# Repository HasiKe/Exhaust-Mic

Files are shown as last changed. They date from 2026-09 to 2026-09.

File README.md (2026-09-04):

# Exhaust-Mic

**Zweikanaliger 24-Bit-Tonrekorder für Motor- und Auspuffgeräusche.**
Zwei Mikrofonköpfe mit 135 dBSPL Grenzschalldruck an einem Stereo-ADC,
aufgezeichnet von einem ESP32-S3 auf microSD — mit Zeitstempeln, die sich
im Schnittprogramm von selbst auf das Videomaterial legen.

Gebaut für eine Suzuki Hayabusa: Kopf A am Endrohr, Kopf B in der Airbox.

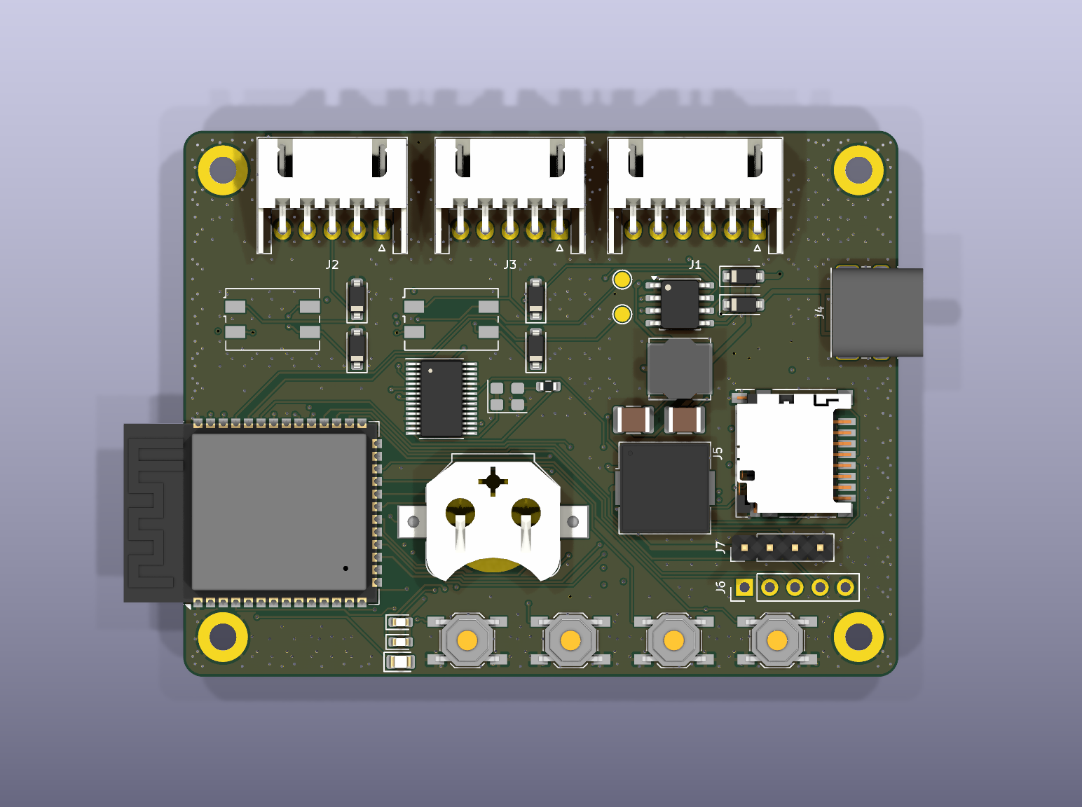
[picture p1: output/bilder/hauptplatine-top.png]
Hauptplatine von oben


---

## Auf einen Blick

| | |
|---|---|
| Kanäle | 2 × differentiell, 135 dBSPL Grenzschalldruck |
| Wandler | PCM1863, 24 Bit, 48 kHz, 110 dB Störabstand |
| Rechner | ESP32-S3-WROOM-1-N8R2, WLAN und Bluetooth LE |
| Speicher | microSD, WAV mit BWF-Zeitstempel |
| Zeitbasis | DS3231-TCXO, ±2 ppm, Sekundenanker auf die Samplenummer |
| Fahrzeug | CAN über SN65HVD230, Zündungs- und Bordnetzerkennung |
| Versorgung | 12 V Bordnetz, LM5164-Abwärtswandler, Verpolschutz |
| Einschalten | Zündung schaltet die Freigabe, Selbsthaltung bis die Datei zu ist, rechnerisch 30 µA im Ruhezustand |
| Hauptplatine | 72 × 55 mm, vier Lagen, beidseitig bestückt |
| Mikrofonkopf | 8 × 27 mm, zwei Lagen, 2× identisch |
| Gehäuse | fünf gedruckte Teile, Rundschnurdichtung |
| Bauteilkosten | rund 65 € Hauptplatine, 4 € je Mikrofonkopf |

## Bilder

| Hauptplatine, Rückseite | Mikrofonkopf |
|---|---|
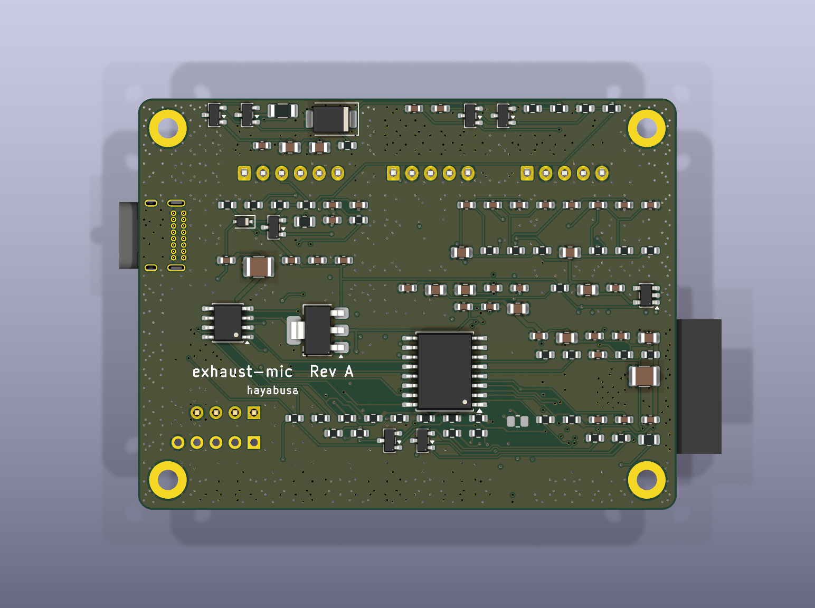
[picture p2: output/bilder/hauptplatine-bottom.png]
Rückseite
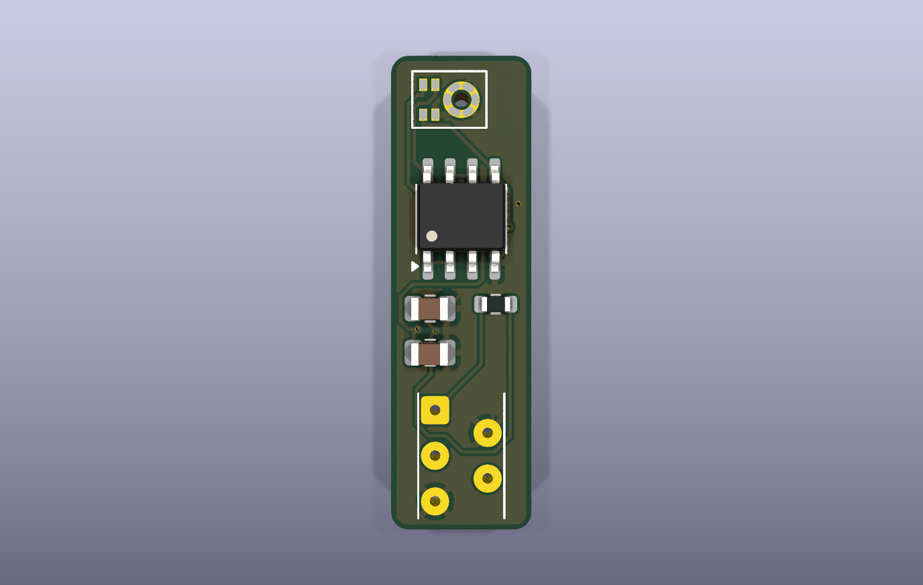
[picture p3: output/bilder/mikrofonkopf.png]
Mikrofonkopf
|  |  |

Alle Kabelstecker sitzen an der oberen Kante und zeigen nach außen, USB-C
und microSD liegen rechts hinter einer gemeinsamen Serviceklappe,
Leuchtdioden und Taster an der unteren Kante. Auf der Rückseite steht
nichts über 2,7 mm — der Aufbau bleibt mit 11,9 mm flach.

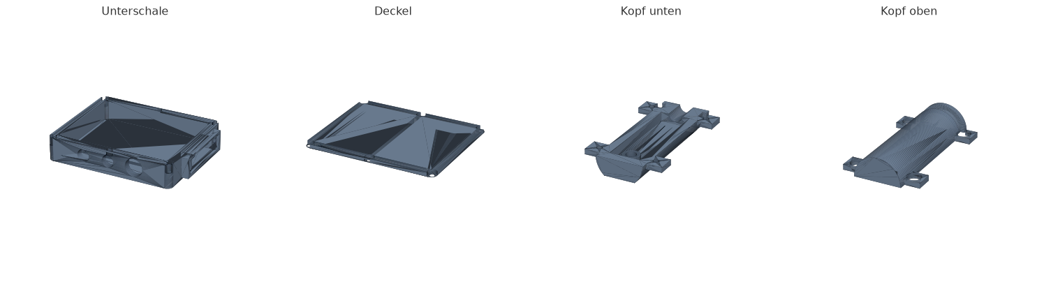
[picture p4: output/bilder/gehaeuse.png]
Gehäuseteile


## Wie das Signal läuft

```
Mikrofonkopf (2×)                    Hauptplatine
┌──────────────────────┐             ┌───────────────────────────────────┐
│ IM73A135  135 dBSPL  │  2× Twisted │  Gleichtaktdrossel + Klemmdioden  │
│   ↓                  │  Pair,      │        ↓                          │
│ OPA2325 Impedanz-    │──geschirmt──│  PCM1863  24 Bit / 48 kHz         │
│ wandler, 2,8-V-LDO   │  4 m        │        ↓ I²S                      │
└──────────────────────┘             │  ESP32-S3 ──► microSD (WAV/BWF)   │
                                     │        ↑                          │
                                     │  DS3231 1 Hz ─ Sekundenanker      │
                                     └───────────────────────────────────┘
```

Der Wandler ist Taktherr und hängt an einem eigenen 24,576-MHz-Oszillator;
der ESP32 empfängt nur. Die Sekundenflanke der Uhr latcht den laufenden
Samplezähler — das ergibt eine driftfreie Zuordnung Wanduhrzeit ↔ Sample
über die ganze Aufnahme, unabhängig vom Abtastratenfehler.

## Stand

| | Mikrofonkopf | Hauptplatine |
|---|---|---|
| Größe | 8 × 27 mm | 72 × 55 mm |
| Bauteile | 14 | 131 |
| Leiterbahnen | 120 (199 mm) | 1085 (3321 mm) |
| Durchkontaktierungen | 7 | 879 |
| Offene Verbindungen | **0** | **8** |
| DRC-Fehler | **0** | **0** |
| ERC-Fehler | **0** | **0** |
| Schaltplanparität | **0** | 6 |
| Bauhöhe oben / unten | 1,8 / 1,5 mm | 7,6 / 2,7 mm |

Der Mikrofonkopf ist fertig. Auf der Hauptplatine bleiben **acht
Verbindungen offen** — allesamt Stücke der Masseflächen, kein Pad und kein
Signalnetz. Sie sind in KiCads interaktivem Router in wenigen Minuten zu
schließen und müssen vor der Fertigung geschlossen sein.

Die sechs Abweichungen der Schaltplanparität sind die vier
Befestigungsbohrungen ohne Symbol und die Schirmanschlüsse von USB-C und
Kartenhalter, die der Footprint führt und das Symbol nicht.

Beschaffung: 71 von 76 Positionen haben eine bei DigiKey lagernde
Herstellernummer. Offen sind zwei: MK1 — das IM73A135V01XTSA1 ist aktiv,
bei DigiKey aber ohne Bestand, andere Distributoren führen es — und **R2
(680 k)**, das beim Umbau auf die Zündungsfreigabe seinen Wert gewechselt
hat und noch keine geprüfte Bestellnummer trägt.

> **Nichts davon ist bisher aufgebaut worden.** Geprüft sind DRC, ERC,
> Schaltplanparität, eine eigene Abnahme und der Übersetzungslauf der
> Firmware — keine Messung an echter Hardware.

## Was im Repository liegt

| | |
|---|---|
| `*.kicad_sch`, `exhaust-mic.kicad_pcb` | Hauptplatine, sechs Blätter |
| `mic-head/` | eigenes Projekt für den Mikrofonkopf |
| `lib/` | Symbole und Landmuster, die KiCad nicht mitbringt |
| `firmware/` | ESP-IDF-Firmware |
| `output/` | Stücklisten, Gerber, PDF, STEP/STL, Bilder |
| `docs/` | Beschaffung, Gehäuse, Entwicklungsnotizen |

Schaltplan, Layout, Gehäuse und die Pinbelegung der Firmware werden
**erzeugt, nicht von Hand gepflegt**. Jede Gehäuseöffnung und jeder GPIO
in der Firmware stammt aus der Platinendatei — wandert ein Stecker,
wandert alles mit. Das hat sich mehrfach ausgezahlt: die Stecker sind in
diesem Projekt zweimal komplett umgezogen.

## Selbst erzeugen

Schaltplan, Layout und Gehäuse entstehen aus Generatorskripten, die
**nicht im Repository liegen** (`tools/`, `case/`). Hier stehen ihre
Ergebnisse: die KiCad-Dateien, die Modelle und alles unter `output/`.
Die Firmware baut ohne sie:

```sh
# Firmware
. ~/esp/esp-idf/export.sh
cd firmware && idf.py set-target esp32s3 && idf.py build
```

⚠️ **Die Dateien auf der Platte sind weiter als die Generatoren.** In den
Schaltplänen stecken Beschaffungsfelder, korrigierte Landmuster, zwei
reparierte Symbole und fünf PWR_FLAG, die `build_main.py` überschreiben
würde. Vor einem Neulauf lesen: [`docs/entwicklung.md`](docs/entwicklung.md).

## Weiterlesen

| | |
|---|---|
| [`docs/beschaffung.md`](docs/beschaffung.md) | Bauteilwahl über die DigiKey-Schnittstelle, Ersatztypen, Bestand |
| [`docs/gehaeuse.md`](docs/gehaeuse.md) | Maße, Dichtkonzept, Filamentwahl, Temperaturgrenze am Endrohr |
| [`docs/entwicklung.md`](docs/entwicklung.md) | Werkzeugfallen, Leiterbahnbreiten, Prüfung, Schaltplan gegen Platine |
| [`firmware/README.md`](firmware/README.md) | Firmware, GoPro-Kopplung, Stand gegen die Anforderungen |
| [`docs/specs/…`](../../docs/specs/2026-08-28-exhaust-mic-design.md) | Auslegung, Rauschbudget, Pegelplan |
| [`CHANGELOG.md`](CHANGELOG.md) | Was in welcher Version dazukam, bekannte Einschränkungen |

## Zündung

Die Freigabe des Abwärtswandlers hängt an **Klemme 15**, die Versorgung
selbst an Klemme 30. Zündung an heißt anlaufen; Zündung aus heißt nicht
sofort stromlos, sondern: der ESP32 hält seine eigene Versorgung über
`PWR_HOLD` fest, schließt die Datei und lässt dann los. Im Ruhezustand
bleiben rechnerisch **30 µA** statt der rund 100 mA, die eine dauernd
laufende Platine zieht — vorher gab es kein Aus.

**Der Motor startet die Aufnahme.** Springt er an, hebt die Lichtmaschine
das Bordnetz von der Ruhespannung auf 14 V — das ist der dritte Auslöser
neben Taster und Kamera. Schwellen und Zeiten stehen in
[`firmware/README.md`](firmware/README.md#zündung-motorlauf-und-abschalten),
die Schaltung in
[`docs/entwicklung.md`](docs/entwicklung.md#die-zündung-schaltet-nicht-das-bordnetz).

## GoPro

Der Rekorder hängt sich über Bluetooth LE an die Open-GoPro-Schnittstelle
und meldet sich für den Kamerastatus an: **Video starten heißt Aufnahme
starten**, Stopp heißt Stopp. Der Taster am Gerät löst umgekehrt die
Kamera aus.

⚠️ Die Platine kann der Kamera **keinen Ton liefern**. Der ESP32-S3
beherrscht nur Bluetooth LE, GoPro nimmt drahtlosen Ton aber über HFP an —
ein Bluetooth-Classic-Profil. Und HFP wäre einkanalig mit 8 oder 16 kHz,
also das Gegenteil dessen, wofür diese Platine gebaut ist. Einzelheiten
und die zwei Auswege in [`firmware/README.md`](firmware/README.md).

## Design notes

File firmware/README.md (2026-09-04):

# Firmware

ESP-IDF v5.3.2, Ziel `esp32s3`. Baut warnungsfrei, 664 kB Abbild.

```sh
git clone --depth 1 -b v5.3.2 --recursive https://github.com/espressif/esp-idf ~/esp/esp-idf
~/esp/esp-idf/install.sh esp32s3
. ~/esp/esp-idf/export.sh
cd firmware && idf.py set-target esp32s3 && idf.py build
idf.py -p /dev/ttyACM0 flash monitor
```

## Die Pinbelegung wird erzeugt, nicht abgetippt

```sh
python3 firmware/tools/pins_aus_netzliste.py     # -> firmware/main/pins.h
```

Quelle ist `output/main.net`, also der Schaltplan. Der Header ist
mitversioniert: ein Diff zeigt sofort, wenn ein GPIO gewandert ist. Von
Hand geändert wird er nicht.

## Zündung, Motorlauf und Abschalten

Die Platine hängt mit `VBAT12` an Klemme 30, ihre Freigabe `EN/UVLO` aber
an Klemme 15 — Zündung an heißt anlaufen. Zündung aus würde den Strom
mitten im Schreiben abstellen, deshalb hält `PWR_HOLD` (GPIO42) die
Freigabe über D8 fest, bis die Datei zu ist. Der Aufbau steht in
[`docs/entwicklung.md`](../docs/entwicklung.md#die-zündung-schaltet-nicht-das-bordnetz).

`zuendung_selbsthaltung()` ist die **erste Zeile in `app_main`** — vor
allem anderen. Beim Anlassen bricht die Zündspannung ein; ohne die
Selbsthaltung fiele die Platine genau dann aus, wenn die Aufnahme
beginnen soll.

Gemessen wird über die beiden Teiler auf dem Versorgungsblatt:

| | Teiler | Bereich |
|---|---|---|
| Klemme 15 | R9 100k / R10 47k, Zenerklemme D5 | brauchbar bis rund 10 V, darüber gekappt |
| Bordnetz | R11 470k / R12 68k | ungekappt bis über 20 V |

Klemme 15 ist damit ein Anwesenheitsmelder, das Bordnetz eine Messung.
Daraus die drei Zustände:

| Zustand | Bedingung | Wirkung |
|---|---|---|
| `ZUENDUNG_AUS` | Klemme 15 unter 5 V für 2 s | Datei schließen, Selbsthaltung lösen |
| `ZUENDUNG_AN` | Klemme 15 über 7 V für 0,3 s | bereit, keine Aufnahme |
| `ZUENDUNG_MOTOR` | Bordnetz über 13,2 V für 2 s | Aufnahme läuft |

**Der Motor ist der dritte Auslöser** neben Taster und Kamera: springt er
an, hebt die Lichtmaschine das Bordnetz von der Ruhespannung (12,6 bis
12,8 V, direkt nach der Fahrt bis 13,0 V) auf 14,0 bis 14,4 V. 13,2 V
trennt beides. Zurück geht es erst unter 12,9 V und nach zehn Sekunden —
im Leerlauf mit Lüfter und Licht bricht die Spannung sonst kurz genug
ein, um die Aufnahme zu zerhacken.

Die Abschaltschwelle für Klemme 15 liegt mit 5 V bewusst tief: beim
Anlassen geht die Zündleitung mit dem Bordnetz in die Knie, und wer hier
9 V ansetzt, schaltet das Gerät genau beim Motorstart ab. Der
Schlüsseldreh dagegen fällt hart auf null.

Am Schreibtisch stört das nichts: `+4V6` kommt über D4 auch aus
`USB_VBUS`, und der Automat schaltet nur ab, wenn er die Zündung vorher
einmal gesehen hat. `PGOOD` sagt zusätzlich, ob der Abwärtswandler
regelt.

⚠️ **Die Werkskalibrierung des ADC ist Pflicht.** Ohne den eFuse-Wert
liegen die Spannungen um bis zu zehn Prozent daneben — das ist genau der
Abstand zwischen Ruhe- und Ladespannung. `zuendung_start()` gibt dann
einen Fehler zurück, statt zu raten.

## GoPro

### Was geht: Aufnahme automatisch mitlaufen lassen

Über Bluetooth LE nach der Open-GoPro-Schnittstelle. Der Rekorder meldet
sich für Statusänderungen an; sobald die Kamera zu kodieren beginnt,
startet die Aufnahme, und umgekehrt. Der Taster am Gerät löst zusätzlich
die Kamera aus.

Alle Kennungen stammen aus dem offiziellen SDK
(`open_gopro/models/constants/`), nicht aus dem Gedächtnis:

| | Wert |
|---|---|
| Dienst | `0000FEA6-0000-1000-8000-00805F9B34FB` |
| Merkmale | `b5f9XXXX-aa8d-11e3-9046-0002a5d5c51b`, XXXX = 0072 Befehl, 0073 Antwort, 0076 Abfrage, 0077 Antwort |
| Auslöser | `SET_SHUTTER` 0x01 |
| Statusabo | `REG_STATUS_VAL_UPDATE` 0x53, Rückmeldung `STATUS_VAL_PUSH` 0x93 |
| Status | `ENCODING` = 10 |

Die Kamera muss beim ersten Mal im Kopplungsmodus stehen
(Einstellungen → Verbindungen → Gerät verbinden).

### Was nicht geht: die Kamera mit Ton beliefern

**Auf dieser Platine unmöglich, aus zwei voneinander unabhängigen
Gründen.**

1. **Der ESP32-S3 kann kein Bluetooth Classic.** Er beherrscht
   ausschließlich Bluetooth LE 5.0; Espressif schreibt für beide
   Host-Stapel ausdrücklich „Classic Bluetooth is not supported". Damit
   gibt es weder A2DP noch HFP. GoPro nimmt drahtlosen Ton aber genau
   über HFP an — so werden AirPods und die DJI Mic 2 im Bluetooth-Modus
   eingebunden.
2. **Selbst wenn es ginge, wäre es ein Rückschritt.** HFP ist ein
   Telefonieprofil: einkanalig, 8 oder 16 kHz. Diese Platine existiert für
   zwei Kanäle mit 24 Bit bei 48 kHz und 135 dBSPL Grenzschalldruck. Der
   Weg über HFP würfe praktisch die gesamte Auslegung weg.

Zwei Auswege, falls der Ton wirklich in die Kameradatei soll:

- **Verkabelt.** GoPro Media Mod oder der 3,5-mm-Adapter am USB-C. Braucht
  einen Analogausgang auf der Platine — den gibt es heute nicht, das wäre
  eine Rev B.
- **Getrennt aufnehmen und im Schnitt zusammenlegen.** Genau dafür ist die
  Zeitbasis gebaut: BWF-Zeitstempel in jeder Datei, Sekundenanker in der
  Begleitdatei, dazu Blitz und Piep als framegenaue Marke. Resolve und
  Premiere ziehen die Spur von selbst an die richtige Stelle. Mit der
  BLE-Kopplung oben passiert das ohne Handgriff.

## Stand gegen die Anforderungen der Spezifikation

| | Anforderung | Stand |
|---|---|---|
| F1 | I2S-Slave-RX per DMA | ✅ `audio.c` |
| F2 | Vorallokierte Datei, Kopf beim Schließen gepatcht | ✅ `speicher.c` |
| F3 | BWF/BEXT mit RTC-Zeit | ✅ `speicher.c` |
| F4 | 1-Hz-Anker latcht den Samplezähler | ✅ `zeitbasis.c` |
| F5 | PCM1863 über I²C, differentiell, Taktherr | ✅ `pcm1863.c` |
| F6 | Übersteuerung mit Anzeige | ✅ Anzeige; automatische Absenkung offen |
| F7 | Zündungsautomat, sauberes Herunterfahren | ✅ `zuendung.c` |
| F8 | Sync-Marker Blitz + Piep, Samplenummer | ✅ `bedienung.c` |
| F9 | WLAN nur außerhalb der Aufnahme, NTP | ❌ offen |
| F10 | CAN über TWAI in die Begleitdatei | ❌ offen |
| F11 | Download über USB-MSC oder WLAN | ❌ offen |
| — | GoPro-Kopplung über BLE | ✅ `gopro.c` |

**Nichts davon lief bisher auf echter Hardware** — es gibt noch keinen
Aufbau. Geprüft ist bisher nur, dass es übersetzt. Die Registerwerte des
PCM1863 stammen aus dem Linux-Treiber `sound/soc/codecs/pcm186x.{c,h}`,
die I²C-Adresse 0x4A folgt aus MS/AD an Masse.

## Aufbau

| Datei | Inhalt |
|---|---|
| `main.c` | Zustandsführung, Aufnahme starten und stoppen |
| `gopro.c` | BLE-Zentral, Open-GoPro-Protokoll |
| `audio.c` | I2S-Empfang, Rahmenzähler, Spitzenwert |
| `pcm1863.c` | Wandler über I²C |
| `speicher.c` | Karte, WAV mit BEXT, Begleitdatei |
| `zeitbasis.c` | DS3231, Sekundenanker |
| `zuendung.c` | Klemme 15 und Bordspannung, Selbsthaltung, Abschalten |
| `bedienung.c` | Taster, Leuchtdioden, Piezo, Marker |
| `i2cbus.c` | gemeinsamer I²C-Strang |
| `pins.h` | erzeugt, siehe oben |

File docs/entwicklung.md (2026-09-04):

# Entwicklungsnotizen

Was beim Bauen schiefging und warum die Werkzeuge so aussehen, wie sie
aussehen. Für alle, die an den Generatoren weiterarbeiten — oder
dieselben Fallen umgehen wollen.

> Die Generatoren selbst (`tools/`, `case/`) liegen **nicht im
> Repository** — die Dateipfade unten benennen sie, ohne dass sie hier
> mitgeliefert würden. Im Repository stehen ihre Ergebnisse.

## Inhalt

- [Die Zündung schaltet, nicht das Bordnetz](#die-zündung-schaltet-nicht-das-bordnetz)
- [Steckverbinder ausrichten](#steckverbinder-ausrichten)
- [Kupfer entfernen ist gefährlich](#kupfer-entfernen-ist-gefährlich)
- [Der Autorouter kennt den Kantenabstand nicht](#der-autorouter-kennt-den-kantenabstand-nicht)
- [Leiterbahnbreiten](#leiterbahnbreiten)
- [Der Mikrofonkopf ist auf ein Fünftel geschrumpft](#der-mikrofonkopf-ist-auf-ein-fünftel-geschrumpft)
- [Prüfen](#prüfen)
- [Schaltplan gegen Platine](#schaltplan-gegen-platine)
- [Bestückungsdruck](#bestückungsdruck)

---

## Die Zündung schaltet, nicht das Bordnetz

Bis Rev A hing `EN/UVLO` des LM5164 über R2/R3 fest an **VBAT12**, und
VBAT12 ist Klemme 30 — Dauerplus. Damit lief die Platine, sobald sie am
Fahrzeug hing: rund um die Uhr, mit dem Ruhestrom des NCP1117, dem
CAN-Treiber, dem Wandler und der Uhr an 3V3. Auf einem Motorradakku ist
das eine Frage von Wochen.

Jetzt speist **IGN_IN** (Klemme 15) den Teiler, und der ESP32 hält seine
eigene Versorgung fest, bis die Datei geschlossen ist:

```
IGN_IN ──[R2 680k]──┬── EN/UVLO (U1)
                    ├──[R3 150k]── GND        Einschaltschwelle
                    ├──[D7 BZX84C3V3]── GND   Klemme
                    │
PWR_HOLD ─┬─[R13 10k]──►|── D8 ───┘           Selbsthaltung
          └─[R14 10k]── GND
```

### Die Freigabeschwelle ist 1,5 V, nicht 1,2 V

Der naheliegende Fehler: 1,2 V aus dem Datenblatt ablesen und rechnen.
1,2 V ist die **FB-Referenz**, nicht die Freigabeschwelle. Für EN/UVLO
gilt (SNVSAU4D, Abschnitt 6.3.9, Gleichungen 13 und 14):

| | Wert | mit R2 680k / R3 150k | mit den alten 1M / 150k |
|---|---|---|---|
| Freigabe steigend | 1,5 V | **8,3 V** | 11,5 V |
| Freigabe fallend | 1,4 V | **7,8 V** | 10,7 V |

11,5 V wären für eine Zündleitung zu hoch: ein halb leerer Akku steht bei
11,8 V, und beim Anlassen bricht das Bordnetz ohnehin ein. 8,3 V liegen
unter jeder brauchbaren Zündspannung und über allem, was noch als „aus"
durchgeht. Unterhalb von 1,1 V an EN geht der Wandler in den Ruhezustand
und zieht **3 µA**.

### Warum eine Diode und ein Ableitwiderstand nötig sind

**D8** trennt den Portpin vom Teiler. Ohne die Diode zöge R13 den
EN-Knoten herunter, solange die Platine aus ist — der Portpin liegt dann
stromlos auf Masse:

    12 V × (150k ‖ 10k) / (680k + 150k ‖ 10k) = 0,16 V

Die Platine würde nie anlaufen. Mit Diode sperrt der Zweig, solange
PWR_HOLD nicht getrieben wird.

**R14** deckt den umgekehrten Fall ab. Der Rücksetzzustand von GPIO42 ist
nicht garantiert frei von einem internen Pullup; läge einer an, hielte
die Platine sich selbst fest und ginge nie wieder aus. 10 k gegen die
45 k des Pullups ergeben 0,6 V an der Anode — zu wenig, um D8 zu öffnen.

Getrieben reicht es dagegen deutlich, gerechnet mit 3,2 V Versorgung und
0,75 V Flussspannung im schlechtesten Fall:

    (3,2 − 0,75) V × (150k ‖ 680k) / (10k + 150k ‖ 680k) = 2,27 V

gegen 1,4 V Haltespannung.

R13 und R14 stehen im Layout beim Funkmodul. Der naheliegendere Platz für
R13 wäre neben D8 gewesen — dann läge der Knoten zwischen Widerstand und
Diode nicht 30 mm lang quer über die Platine. Das Band unter dem Regler
war damit aber überfüllt: dem Router fehlte der Ausweg, und **SD_CLK**
zwischen U6 und dem Kartenhalter blieb offen. Die Leitung führt eine
Gleichspannung aus einem Gegentaktausgang über eine durchgehende
Massefläche; 30 mm sind dafür ohne Belang, eine offene Taktleitung zur
Karte nicht.

### Kein Stützkondensator

Der Wandler hängt mit VIN weiter an Klemme 30. Geschaltet wird nur seine
Freigabe — die Energie steht während der ganzen Nachlaufzeit an. Eine
Selbsthaltung, die den Versorgungspfad selbst auftrennt, bräuchte einen
Puffer für die Sekunde, die das Schließen der Datei dauert; diese hier
nicht.

### D7 ist für die negativen Pulse da

Naheliegende Annahme: der Zener schützt EN gegen Überspannung. Das ist
nicht nötig — **EN verträgt −0,3 bis 100 V** (SNVSAU4D, Abschnitt 5.1),
und ein 60-V-Puls kommt über den Teiler nur auf 10,8 V.

Die untere Grenze ist das Problem. ISO 7637-2 kennt Pulse bis −100 V, und
bei −0,3 V ist am EN-Pin Schluss. In dieser Richtung leitet der Zener in
Flussrichtung und klemmt auf −0,7 V; der Strom über R2 bleibt bei 150 µA.
Für den Preis eines SOT-23, das ohnehin zweimal auf der Platine steckt.

### Ruhestrom

Bisher gab es kein Aus. Lag Bordspannung an, lief die Platine — und zwar
nicht im Leerlauf, sondern vollständig: ESP32 wach, Wandler getaktet,
CAN-Treiber aktiv, Karte eingehängt. Die Größenordnung liegt damit im
Bereich **100 mA**, nicht im Mikroampere-Bereich.

Jetzt bleibt bei abgezogener Zündung stehen:

| | Quelle | Strom |
|---|---|---|
| LM5164 im Ruhezustand | Datenblatt, Abschnitt 6.4.1 | 3 µA |
| Teiler `VBAT_SENSE` (470 k + 68 k) | 14,4 V / 538 kΩ | 27 µA |
| Teiler EN (jetzt an Klemme 15) | Klemme 15 ist spannungslos | 0 |
| TVS D2, Zener D1, PMOS Q1 | Sperrströme | wenige µA |
| **zusammen** | | **rund 30 µA** |

⚠️ Alle Werte sind **gerechnet**, nicht gemessen — es existiert kein
Aufbau. Der Punkt ist aber nicht die zweite Stelle hinter dem Komma: der
Unterschied zwischen „läuft durch" und „30 µA" ist der zwischen Tagen und
Jahren, bis der Akku leer ist.

Vorher hätte der EN-Teiler an VBAT12 selbst noch 13 µA gezogen
(14,4 V / 1,15 MΩ) — neben allem anderen war das der kleinste Posten.

### USB bleibt davon unberührt

`+4V6` bekommt über D4 auch Strom aus `USB_VBUS`. Am Schreibtisch läuft
die Platine also ohne Zündung weiter, und der Automat merkt das: er
schaltet nur ab, wenn er die Zündung vorher einmal gesehen hat. `PGOOD`
sagt zusätzlich, ob der Abwärtswandler regelt — der Pin hat **keinen
äußeren Pullup**, die Firmware schaltet den im Modul zu.

### Was beim Einbau schiefging

- **An eine `.kicad_sch` anhängen geht nicht.** Alles hinter der
  schließenden Klammer des Blattes liest KiCad wortlos nicht mehr. Die
  Datei öffnet sich, das ERC läuft, und die Netzliste meldet nur
  unverbundene Pins. Eingefügt wird vor `(sheet_instances`.
- **Ein leeres Feld ist nicht dasselbe wie kein Feld.** R2 bekam beim
  Wertwechsel ein leeres `DigiKey`-Feld. Leere Felder fallen aus der
  Netzliste heraus, und die Schaltplanparität meldete daraufhin
  „Fehlendes Symbolfeld DigiKey in Footprint". Das Feld muss ganz weg.
- **Die Regionen von `pack()` sind enger, als sie aussehen.** Drei Teile
  zusätzlich in „Buck-Umgebung" schoben C12 an eine Stelle, an die der
  Router nicht mehr herankam — der 100n am 3V3D-Zweig blieb offen. Das
  Band unter dem Regler beginnt deshalb jetzt bei x = 41 statt bei x = 43,
  und die drei Teile stehen woanders.
- **Feines Vernähen ist kein Gewinn.** Ein Rastermaß von 1,6 und 1,3 mm
  schloss zwei Massestücke, brachte aber 800 zusätzliche
  Durchkontaktierungen und 27 Regelfehler mit. Bei 2,0 mm ist Schluss.

## Steckverbinder ausrichten

Bei `rot=0` zeigt die Öffnung eines Kantensteckers auf **+y**, nicht auf −y.
Die Annahme war einmal andersherum, und dadurch zeigten J1 bis J4 mit der
Öffnung ins Platineninnere; beim USB-C-Anschluss war die Buchse damit gar
nicht erreichbar. Der Footprint sagt es selbst:

| Footprint | Woran man es sieht |
|---|---|
| `JST_XH_S*B-XH-A_..._Horizontal` | Der F.Fab-Umriss hat zwischen den beiden Seitenohren eine Aussparung von y −2,3 bis +2,2 — dort treten die Stifte nach unten aus. Die Kontaktkanäle laufen von y 3,2 bis 8,7 nach vorn, die Frontfläche liegt bei y = +9,2. |
| `USB_C_Receptacle_GCT_USB4085` | Eine Linie auf `Dwgs.User` mit der Aufschrift **PCB Edge** bei y = +6,1. Dort muss die Platinenkante liegen, die Nase ragt bis y = +8,61 darüber hinaus. |
| `microSD_HC_Hirose_DM3D-SF` | Der Kartenumriss auf F.Fab reicht bis y = +10,08, der Halterkörper endet bei +5,73. Die Karte steht also 4,35 mm heraus — das Kollisionsrechteck von `place()` muss diesen Kanal enthalten, sonst stellt `pack()` etwas darunter. |

Für die Kante gilt damit:

| Kante | Drehung |
|---|---|
| oben (−y) | 180 |
| rechts (+x) | 90 |
| unten (+y) | 0 |
| links (−x) | 270 |

Vor jeder Platzierung eines Kantensteckers die Marke oder die Aussparung im
Footprint nachsehen, nicht raten.

## Kupfer entfernen ist gefährlich

Drei Werkzeuge nehmen Kupfer weg — `fix_drc.py`, `cleanup.py`,
`trim_warnings.py`. Alle drei können dabei Verbindungen aufreißen, und zwar
aus demselben Grund: **ein Segment, das nirgends an einem Pad hängt, kann
trotzdem tragen.** Läuft es quer durch eine gefüllte Massefläche, verbindet
es deren Stücke miteinander. Der Test „beide Enden frei in der Luft" sieht
das nicht.

Pauschal entfernt hat das die offenen Verbindungen von 7 auf 9 gehoben.
`cleanup.py` zählt deshalb nach: wird es nach dem Entfernen schlechter,
kommt alles zurück und jedes Segment wird einzeln probiert. `fix_drc.py`
zerstört weiterhin ein bis zwei Verbindungen je Lauf — dafür laufen die
Nachbesserungen ein zweites Mal.

Ebenso setzten `handroute.py` und `stitch.py` ihre Durchkontaktierungen
früher ohne Blick auf die Kontur. Zwei Nähvias landeten 0,7 mm neben dem
Anker der Massefläche bei (0,3 / 0,3) und damit **außerhalb der Platine** —
Kupfer, das die Fräse wegnimmt. `pcbgen.inside_outline()` prüft jetzt acht
Punkte auf dem Rand des Vias gegen das Konturpolygon; ein Mittelpunkttest
allein übersieht die abgerundeten Ecken.

## Der Autorouter kennt den Kantenabstand nicht

freerouting hält zur Begrenzung nur den allgemeinen Abstand ein — hier
0,15 mm. KiCad verlangt zur Platinenkante aber 0,25 mm
(`min_copper_edge_clearance`). Auf dem 8 mm schmalen Kopf hat der Router
deshalb drei Bahnen mit 0,23 mm an die rechte Kante gelegt: drei
Regelfehler, nachträglich nur durch Aufreißen der Bahn zu beheben.
`route.py` rückt die Begrenzung im DSN jetzt um 0,12 mm ein, bevor
freerouting startet — gerechnet auf den Koordinaten im DSN selbst, damit
offen bleibt, wo KiCad den Nullpunkt hingelegt hat.

## Leiterbahnbreiten

freerouting verlegt alles in der Vorgabebreite von 0,18 mm. Für Signale ist
das richtig, für den Versorgungspfad nicht: 0,18 mm bei 35 µm Außenkupfer
tragen nach IPC-2221 rund 0,5 A bei 10 K Erwärmung, der ESP32 zieht in
Sendespitzen annähernd 0,5 A allein. `widen_supply.py` weitet deshalb im
Nachgang auf — gestaffelt und gruppenweise, die Gruppe mit dem größten Strom
zuerst, damit sie den Platz bekommt:

| Gruppe | Ziel |
|---|---|
| Schaltknoten, Buck-Ausgang, +4V6, +3V3D | 0,5 mm |
| Bordnetzeingang, VBAT12, USB_VBUS, GND | 0,4 mm |
| +3V3A | 0,3 mm |

Zurückgenommen wird nach **KiCads** Regelprüfung, nicht nach der Näherung in
`pcbgen.py`: die kennt die tatsächlichen Padformen nicht und lässt Bahnen
durchgehen, die an einer Kühlfahne zu nah liegen. Zwei Fallen dabei, beide
teuer bezahlt:

* Nur auf `clearance` zu filtern reicht nicht. Eine aufgeweitete Bahn kann
  ein fremdes Pad überdecken, und das meldet KiCad als **Kurzschluss** oder
  als Brücke im Lötstopplack. Beim ersten Versuch blieben so fünf echte
  Kurzschlüsse stehen, während das Werkzeug „keine Abstandsfehler mehr"
  meldete.
* Je Verstoß wird höchstens **eine** Bahn verschmälert, die breitere der
  beteiligten. Nimmt man beide zurück, verliert man an jeder engen Stelle
  doppelt.

Was danach noch bei 0,18 mm liegt, lässt sich ohne neues Routing nicht
verbreitern — der Nachbar steht im Weg. Der auffälligste Rest ist eine
24 mm lange USB_VBUS-Strecke auf In2 zwischen zwei SD-Datenleitungen: bei
0,5 A aus dem USB-Anschluss rund 23 K Erwärmung. Das passiert nur am
Schreibtisch, nicht auf der Fahrt.

`stitch.py` und `handroute.py` nehmen die offenen Verbindungen aus
`kicad-cli pcb drc` statt aus eigener Vermutung und lehnen jeden Weg ab,
der die Abstandsregel verletzt. Bei `handroute.py` ist die Prüfung auf
gleiche Netznamen nicht optional: KiCad nennt in „Missing connection
between items" gelegentlich ein zweites Element aus einem fremden Netz —
ohne die Sicherung entsteht daraus ein Kurzschluss.

Seit KiCad 10 kommen die eingebauten Prüfungen dazu — die gab es in
Version 7 noch nicht:

```sh
kicad-cli sch erc --severity-error exhaust-mic.kicad_sch
kicad-cli pcb drc --severity-error --schematic-parity exhaust-mic.kicad_pcb
```

`build_pcb.py --map` zeichnet eine grobe ASCII-Belegungskarte je Seite —
damit lässt sich die Aufteilung beurteilen, ohne KiCad zu öffnen.

Große und mechanisch gebundene Teile stehen im Bestückungsplan fest, alles
andere sortiert `pack()` regalweise in benannte Regionen. Das überlebt
Änderungen an einzelnen Footprints, ohne dass 127 Koordinaten nachgeführt
werden müssen.

`route.py` braucht [freerouting](https://github.com/freerouting/freerouting)
**v1.9.0** als `fr-1.9.0.jar` im Arbeitsverzeichnis, dazu `xvfb-run` —
freerouting baut auch im Stapelbetrieb eine Oberfläche auf und bricht ohne
Display ab. Die JAR-Datei liegt bewusst nicht im Repository, sie ist
Fremdsoftware mit eigener Lizenz.

Bewusst **nicht** die neuere v2.1.0: die schreibt die SES-Datei erst am
Ende des Laufs, endet aber nur, wenn sie auf null offene Verbindungen
kommt. Bleibt ein Rest, dreht sie endlos — `max_passes`, `stop_pass_no`,
`job_timeout` und `optimizer.max_passes` werden allesamt ignoriert
(beobachtet bis Durchgang 434). Ein Abbruch von außen verwirft dann das
komplette Routing. v1.9.0 hält sich an `-mp`.

## Der Mikrofonkopf ist auf ein Fünftel geschrumpft

Von 22 × 40 mm auf **8 × 27 mm**, 880 mm² auf 216 mm². Dieselben vierzehn
Bauteile. Drei Dinge haben den Platz gekostet:

| Was | Ersparnis |
|---|---|
| Lötpad-Landmuster mit Zugentlastung, 20,05 × 13,27 mm | 228 mm² |
| Alles auf der Oberseite | rund die Hälfte der Restfläche |
| Zwei M2,2-Bohrungen mit 4 mm Pad an der Unterkante | rund 5 mm Länge |

Das Landmuster war der größte Posten: 266 mm² für einen einzigen Steckplatz,
mehr als die anderen dreizehn Bauteile zusammen (121 mm²). Fünf Pads
nebeneinander sind allein 20 mm breit und haben damit die Platinenbreite
diktiert. `lib/exhaust-mic.pretty/SolderWire-0.1sqmm_1x05_2reihig_P2.6mm`
setzt sie zweireihig versetzt auf 5,15 × 7,35 mm; die Drähte laufen jetzt
längs aus der Platine heraus statt quer, was für einen Kopf im Röhrchen
ohnehin die richtige Richtung ist.

Zwei Stolpersteine beim Umbau:

- **Die Durchsteckpads sperren die Rückseite auf ihrer ganzen Fläche.** Der
  erste Entwurf stellte die Kleinteile hinter die Kabelpads, `check()`
  meldete fünf Kollisionen. C1, C4 und FB1 sitzen deshalb vorn im freien
  Feld zwischen Wandler und Kabelpads.
- **Bei 8 mm Breite muss ein Kanal frei bleiben.** Erst blieb `OUT_P` als
  einziges Netz offen, weil der Regler U1 links im Weg stand — `OUT_N` kam
  rechts durch. Ab y 9,9 ist auf der Rückseite alles nach rechts gerückt;
  links bleiben 2,7 mm für die Bahn von R1 zu den Kabelpads.

## Prüfen

```sh
kicad-cli sch export netlist --output /tmp/exhaust-mic.net exhaust-mic.kicad_sch
kicad-cli sch export pdf     --output /tmp/exhaust-mic.pdf exhaust-mic.kicad_sch
python3 tools/build_bom.py /tmp/exhaust-mic.net output/bom-mainboard.csv
```

Die Netzliste ist die eigentliche Abnahme des Schaltplans: jedes Netz und
jeder offene Pin lassen sich gegen Abschnitt 7 und 10 der Spec abgleichen.
Aktuell bleiben 19 Pins bewusst offen (Strapping-Pins des ESP32, unbenutzte
Analogeingänge des PCM1863, die laut Datenblatt ausdrücklich nicht beschaltet
werden dürfen, und ungenutzte Funktionspins).

Für das Layout gibt es kein `kicad-cli pcb drc` in Version 7. Die Abnahme
läuft deshalb über drei eigene Prüfungen in `pcbgen.py`, die bei jedem Lauf
mitlaufen:

| Prüfung | Was sie findet |
|---|---|
| `check()` | Courtyard-Überschneidungen, Teile über der Kontur oder über einer Bohrung, Pads ohne Netz |
| `connectivity_report()` | getrennte Kupferinseln je Netz — KiCad 7 gibt über Python nur die Gesamtzahl heraus, nicht welche |
| `drc_report()` | Abstände Kupfer gegen Kupfer und gegen die Platinenkante |

`drc_report()` modelliert Pads als Strecke mit halber Breite statt als
Umkreis. Mit dem Umkreis meldet jedes Nachbarpad eines SOIC-Gehäuses eine
Verletzung, und echte Fehler gehen im Rauschen unter.

### Schaltplan gegen Platine

Die Footprints im Schaltplan sind auf den Stand des Layouts gezogen: U5 auf
`TSSOP-30_4.4x7.8mm_P0.5mm` (so steht es im Datenblatt), U6 auf das
S3-Modul, L2/L3 auf `L_CommonMode_Wuerth_WE-SL2`, J1–J3 auf JST XH
(Superseal 1.0 sitzt im Kabelbaum, es gibt sie nicht als Platinenversion),
BT1 auf den 12-mm-Halter und LS1 auf den 9 × 9 mm großen SMD-Piezo. Wo sich
damit das Bauteil ändert, sind Wert und Bestellnummer mitgezogen — BT1 ist
jetzt **CR1220** statt CR2032, also rund ein Viertel der Kapazität für die
Uhr-Pufferung.

Umgekehrt ist **J4** dem Bauteil gefolgt: den XKB-Typ führt DigiKey nicht,
also sitzt dort jetzt der GCT USB4085-GF-A und im Layout dessen Landmuster.
Das ist kein Tausch gleicher Bauform — der XKB klebt mit einer Padreihe
oben auf, der GCT steckt mit sechzehn Anschlüssen in zwei versetzten Reihen
durch die Platine. Mechanisch ist das am Motorrad die bessere Wahl; dafür
sperren die Bohrungen alle vier Lagen, und das Layout musste an der Stelle
neu. Auf der Rückseite ragen die Stifte heraus — das Gehäuse braucht dort
Luft. Der Autorouter ist danach einmal komplett durchgelaufen und kam auf
**fünf** offene Verbindungen statt der sieben vorher.

Die beiden Symbolfehler sind ebenfalls behoben (`tools/fix_symbols.py`):

* **U2** trug ein Symbol mit vier Pins. Das SOT-223 hat drei Anschlüsse und
  eine Kühlfahne, die innen an Pin 2 hängt — Pin 4 gab es nie. Er lag am
  selben Netz wie Pin 2, elektrisch also folgenlos, und ist samt seiner
  beiden Drähte und dem Verbindungspunkt heraus. Damit ist auch der
  ERC-Fehler „Stromausgang gegen Stromausgang" weg.
* **J5** verwendete `Micro_SD_Card_Det1`. Dieses Symbol kennt einen
  Schaltkontakt und legt den Schirm auf Pin 10. Der DM3D-SF hat zwei
  Schaltkontakte (Pad 9 und 10) und den Schirm auf Pad 11. Jetzt steht dort
  `Micro_SD_Card_Det2`; die gemeinsamen Pins liegen an denselben Stellen,
  der neue Pin 10 (DET_A) ist an Masse gelegt.

KiCads Abgleich meldet danach noch **4 Abweichungen** auf der Hauptplatine
und **2** auf dem Mikrofonkopf — ausschließlich die Befestigungsbohrungen
H1–H4 beziehungsweise H1–H2, die absichtlich kein Symbol im Schaltplan
haben.

Die fehlenden `PWR_FLAG` sind gesetzt (`tools/add_pwr_flags.py`): an **+4V6**,
an **AVDD** (U5 Pin 8) und an **VBAT** (U7 Pin 14) auf der Hauptplatine, am
Reglereingang und an Masse beim Mikrofonkopf. KiCad prüft, ob jedes
Versorgungsnetz von einem Ausgang gespeist wird; diese fünf Netze kommen aus
einer Ferritperle, aus der Knopfzelle oder über das Kabel herein, also aus
etwas, das KiCad nicht als Quelle erkennt. Das Flag sagt dem ERC, dass das
Absicht ist — an der Schaltung ändert es nichts.

**ERC ist damit auf beiden Platinen fehlerfrei.**

Offen sind außerdem Gehäuse und Firmware.

## Bestückungsdruck

Der Siebdruck trägt nur die Steckverbinder-Bezeichner. Alles andere —
Referenzen der Kleinteile, Werte, Herstellernummern — liegt auf der
Fab-Lage: zwischen zwei 0603-Bauteilen sind 0,5 mm, ein lesbarer Bezeichner
passt dort nicht hin, ohne das Nachbarpad zu überdrucken. Für die
Bestückung ist deshalb die Fab-Lage im PDF maßgeblich.

Beschaffungsfelder werden beim Platzieren automatisch unsichtbar gesetzt
und auf die Fab-Lage gelegt. Ohne das landen sie sichtbar im Siebdruck und
überdecken die halbe Platine — das waren 151 der ursprünglich 214
Regelwarnungen.

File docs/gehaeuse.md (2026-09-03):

# Gehäuse

| Teil | Maße | Volumen |
|---|---|---|
| `hauptgehaeuse-unterschale` | 94,0 × 73,4 × 16,6 mm | 34,6 cm³ |
| `hauptgehaeuse-deckel` | 89,0 × 73,4 × 8,7 mm | 16,4 cm³ |
| `hauptgehaeuse-serviceklappe` | 2,0 × 43,0 × 9,6 mm | 0,8 cm³ |
| `mikrofonkopf-unterschale` | 23,0 × 39,0 × 5,4 mm | 1,9 cm³ |
| `mikrofonkopf-oberschale` | 23,0 × 39,0 × 7,0 mm | 2,2 cm³ |

### Was das Hauptgehäuse groß macht

72 × 55 mm Platine, aber 94 × 73 mm außen. Drei Posten:

| Posten | Kostet |
|---|---|
| Antennenüberstand des WROOM-1 nach links | 6,55 mm |
| Kabelkanal vor den Steckern für die Hutmuttern | 8,00 mm |
| 5 mm Wand, zweimal je Achse | 10,00 mm |
| Verdickung für die Serviceklappe rechts | 5,00 mm |

Die Wand ist mit 5 mm dicker als üblich, weil die Dichtnut 2,6 mm breit
ist und beidseitig 1,2 mm Steg braucht. Ein dünnerer Rand mit angesetztem
Flansch wäre leichter, aber der Absatz nach außen ist beim Drucken ein
Überhang. Der Kabelkanal ist nicht verzichtbar: die Steckergehäuse
beginnen 0,8 mm hinter der Platinenkante, die Hutmuttern der
Verschraubungen brauchen davor Platz.

### Dichtheit ohne Durchbrüche

- **Taster**: über jedem Taster steht der Deckel nur 0,7 mm stark, darunter
  ein Stempel Ø4,0 bis 0,3 mm über die Tasterkappe. Die Membran federt, die
  Dichtung bleibt geschlossen. Schaltweg des TL3342 ist 0,25 mm — das
  schafft eine 0,7-mm-Membran über Ø9,0. Ein Durchbruch mit Stößel und
  O-Ring wäre präziser, aber vier weitere Leckstellen.
- **Leuchtdioden**: 0,6 mm Restwand statt Loch. Nur mit lichtdurchlässigem
  Filament sinnvoll; sonst die Tasche durchbohren und Lichtleiter einsetzen.
- **USB-C und microSD** liegen hinter einer gemeinsamen Serviceklappe mit
  eigener Dichtschnur. Die Nase der USB-Buchse ragt ohnehin 3 mm in die
  Wand hinein.
- **Dichtung**: Rundschnur Ø2,0 mm, rund 290 mm Umfang, abgelängt und
  stumpf geklebt. Für diesen Umfang gibt es keinen O-Ring von der Stange.

### Der Mikrofonkopf verträgt kein PLA und kein PETG

⚠️ **Das Mikrofon ist auf 85 °C begrenzt.** Für Kopf B in der Airbox ist
das unkritisch. Kopf A am Endrohr braucht ein Filament, das mindestens so
viel aushält wie das Mikrofon:

| Filament | Formbeständig bis etwa | Kopf A |
|---|---|---|
| PLA | 55 °C | nein |
| PETG | 75 °C | nein |
| ASA / ABS | 95 °C | brauchbar, UV-fest |
| PC, PA-CF | 110 °C und mehr | besser |

Das Gehäuse ist damit nicht das begrenzende Teil, aber es darf auch nicht
das schwächste sein. Für die Hauptplatine am Heck ebenfalls ASA: PETG
kreidet unter UV.

Offen bleibt O4 aus der Spezifikation — die zulässige Einbauposition von
Kopf A muss vor der Endmontage mit einem Thermoelement ausgemessen werden.
Hitzeschild und Abstandshalter sind **nicht** Teil dieser Lieferung.

Die Dichtheit macht das Gehäuse, nicht die Platinensteckverbinder: Superseal
1.0 gibt es nur mit 26, 34 oder 60 Wegen als Platinenheader, die kleinen 5-
und 6-poligen sind reine Kabelsteckverbinder. Auf der Platine sitzen deshalb
JST XH, und die Superseal-Trennstellen wandern ins Kabel.

Vorgesehen ist ein IP67-Kunststoffkasten von etwa 80 × 62 × 25 mm mit
Kabelverschraubungen. Zwei Punkte sind dabei bindend:

- Der Mikrofonkopf hat **keine Befestigungsbohrungen und keine
  Zugentlastung** mehr. Beides muss das Röhrchen übernehmen: Platine
  klemmen oder vergießen, und den Kabelzug abfangen, bevor er an den
  Lötstellen zieht. Rund um die Schallbohrung bleibt die Rückseite bis
  y 5,7 mm frei — dort dichtet das Röhrchen ab; Bauteile stehen erst
  darüber.
- Die Antenne des ESP32-Moduls ragt 6 mm über die linke Platinenkante. Dort
  muss das Gehäuse ausgespart und metallfrei sein. Bei einem Metallgehäuse
  stattdessen den pinkompatiblen ESP32-S3-WROOM-1**U** mit externer Antenne.
- Die microSD-Karte sitzt so weit innen, dass ihre Spitze im
  eingeschobenen Zustand 0,5 mm **vor** der Platinenkante endet. Sie steht
  also nicht über und braucht keine Aussparung, wohl aber einen Schlitz im
  Deckel, durch den man sie einführt. Für den laufenden Betrieb ist der
  Download über WLAN vorgesehen.
- ⚠️ **Die USB-C-Buchse ragt 2,51 mm über die rechte Kante — das gehört so
  und darf nicht „korrigiert" werden.** Der GCT USB4085 ist laut Datenblatt
  eine *Dip Type, PCB Top Mount*; im *Recommended PCB Layout* auf Blatt 2
  zeichnet GCT eine durchgezogene Linie als Platinenkante und lässt den
  Bauteilumriss darüber hinausragen. KiCad hat diese Linie als `PCB Edge`
  auf Dwgs.User übernommen, bei lokal y = +6,1. Grund: die Buchse steht nur
  rund 3,5 mm über der Platine, die Umspritzung eines USB-C-Steckers ist
  aber etwa 6,5 mm hoch und mittig auf der Steckachse — ihre untere Hälfte
  liegt unterhalb der Platinenoberfläche. Reicht die Platine dort hin, stößt
  der Stecker gegen die Kante, bevor er einrastet. Das Gehäuse braucht an
  dieser Stelle ohnehin eine Öffnung; die Buchse ragt in sie hinein.
  Wer den Überstand wirklich loswerden will, braucht eine andere Bauform
  (senkrechte Buchse oder eine bündig aufsetzende SMD-Variante), nicht eine
  andere Position.

Anordnung der Bedienteile:

| Wo | Was |
|---|---|
| obere Kante | Mikrofon A, Mikrofon B, Bordnetz — drei JST XH nebeneinander, Kabel gehen alle in dieselbe Richtung ab |
| rechte Kante | USB-C oben, microSD darunter |
| untere Kante | drei Leuchtdioden als Säule, daneben die vier Taster in einer Reihe |
| Rückseite | nur flache Bauteile, nichts über 2,7 mm |

⚠️ Damit liegt das Bordnetzkabel mit 12 V, CAN und dem geschalteten Strom
des Buck-Wandlers **1,5 mm neben den Mikrofonleitungen**. Auf der Platine
ist das beherrscht — Gleichtaktdrosseln und Klemmdioden sitzen direkt hinter
J2 und J3, und der Regler steht am anderen Ende —, im Kabelbaum aber nicht:
dort gehören die Mikrofonleitungen geschirmt und getrennt vom Versorgungs-
strang geführt. J1 hat sechs Wege, J2 und J3 fünf; vertauschen kann man sie
nicht. J2 und J3 sind untereinander gleich, ein Tausch dreht nur die Kanäle.

Bauhöhe: Oberseite 7,6 mm (JST XH), Rückseite 2,7 mm (DS3231 im SOIC-16W).
Mit 1,6 mm Platine sind das **11,9 mm** Gesamtaufbau. Vorher saß die
Knopfzelle mit 4,3 mm hinten, das waren 13,5 mm. Die beiden stehenden
Stiftleisten J6 und J7 ragen 8,5 mm heraus und sind damit das höchste auf
der Platine; J6 (GPS) ist unbestückt, J7 (I2C-Erweiterung) lässt sich bei
Platznot durch eine liegende Bauform ersetzen.

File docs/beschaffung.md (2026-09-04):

# Beschaffung

Die Bauteilfelder **MPN**, **Hersteller** und **DigiKey** stehen in den
Schaltplänen und wandern von dort in die Stückliste. Sie werden nicht von
Hand gepflegt, sondern gegen DigiKeys Produktdatenbank ermittelt — mit
Lagerfilter, damit nichts in der Stückliste steht, was man nicht bestellen
kann.

> Die `tools/`-Skripte liegen **nicht im Repository**. Der Ablauf ist hier
> beschrieben, seine Ergebnisse stehen in den Schaltplänen und unter
> `output/`.

```sh
set -a; . ~/.config/secrets.env; set +a     # DIGIKEY_CLIENT_ID / _SECRET
kicad-cli sch export bom \
    --fields 'Reference,Value,Footprint,MPN,${QUANTITY}' \
    --labels 'Referenzen,Wert,Footprint,MPN,Menge' \
    --group-by 'Value,Footprint,MPN' -o /tmp/grp-main.csv exhaust-mic.kicad_sch
python3 tools/pick_digikey.py /tmp/grp-main.csv /tmp/grp-mic.csv \
        -o tools/digikey-wahl.json
python3 tools/apply_digikey.py tools/digikey-wahl.json
python3 tools/build_bom.py output/main.net output/bom-mainboard.csv
```

`pick_digikey.py` prüft jeden Treffer gegen die Parameter, die DigiKey selbst
mitliefert — Kapazität, Spannungsfestigkeit, Dielektrikum, Widerstandswert,
Toleranz, Bauform. Die Stichwortsuche allein reicht nicht: auf „10 kOhm 1 %
0603“ antwortet DigiKey auch mit 11,5 k in 0201. Was aus der Schaltung kommt
und nicht in der Stückliste steht (100 V am Bordnetzeingang, C0G im Filter,
1 % am Reglerteiler), steht in der Tabelle `SPEC`; Mechanik und
Steckverbinder in `MANUELL`; nicht lagernde Typen mit ihrem Ersatz und der
Begründung in `ERSATZ`.

`apply_digikey.py` schreibt die Felder in die **vorhandenen** Schaltplandateien
— es erzeugt nichts neu. Vorhandene Hinweise bleiben stehen und werden
ergänzt, nicht überschrieben.

Ändert sich mit dem Bauteil auch das Landmuster, tauscht
`tools/swap_footprint.py` es auf der Platine und ordnet die Netze **über die
Padnamen** aus der Netzliste zu — die Reihenfolge stimmt zwischen zwei
Bibliotheken nie. Danach räumt `fix_drc.py` das Kupfer weg, das dem neuen
Landmuster im Weg liegt, und `tools/trim_warnings.py` entfernt lose
Bahnenden und zu dicht gesetzte Bohrungen. Letzteres geht einzeln vor: was
der Prüfer „lose" nennt, kann nach dem Füllen der Flächen doch tragen, und
pauschales Löschen hat die Zahl der offenen Verbindungen schon einmal
erhöht.

`output/beschaffung-digikey.csv` hält Bestand, Einzelpreis und Ersatzgrund zum
Abfragezeitpunkt fest. Preise und Bestände altern; die Datei ist ein Beleg,
keine laufende Quelle.

## Stand der Bestellliste

behalten.

Beschaffung: von 76 Stücklistenpositionen brauchen drei kein Bauteil (TP1,
TP2, Lötpads am Mikrofonkopf), 71 haben eine bei DigiKey lagernde
Herstellernummer — Stand 31.08.2026, siehe `output/beschaffung-digikey.csv`;
rund 65 EUR Bauteilkosten für die Hauptplatine und 4 EUR für den
Mikrofonkopf. Elf Positionen weichen auf einen gleichwertigen Ersatz aus,
weil der eingetragene Typ leer war; bei fünf davon ist auch der `Value`
nachgezogen (U2 → NCP1117ST33, U3 → LP5907MFX-3.3, U8 → SN65HVD230Q,
Q1 → SI2309CDS, U1 am Mikrofonkopf → LP5907MFX-2.8). Der Grund steht jeweils
im Feld `Hinweis` des Bauteils und damit auch in der Stückliste.

Bestände altern schnell: PCM1863DBTR und TPS7A2028PDBVR waren am Vormittag
noch lagernd und am Abend leer. Beide sind auf gleichwertige Typen umgestellt
(PCM1863**Q**DBTR**Q1** in Automotive-Qualifizierung, LP5907MFX-2.8). Vor
einer Bestellung lohnt ein erneuter Lauf von `pick_digikey.py`.

Zwei Positionen bleiben offen:

| Position | Grund |
|---|---|
| MK1 | IM73A135V01XTSA1 ist aktiv, aber bei DigiKey ohne Bestand; ein Ersatz mit gleichem Gehäuse und Schallöffnung von unten existiert nicht. Andere Distributoren führen ihn. |
| R2 | Beim Umbau auf die Zündungsfreigabe von 1 M auf **680 k** gewechselt (siehe [`entwicklung.md`](entwicklung.md#die-zündung-schaltet-nicht-das-bordnetz)). Eingetragen ist `ERJ-3EKF6803V` aus derselben Panasonic-Reihe wie vorher; die DigiKey-Nummer und der Bestand sind **nicht geprüft** — dafür fehlten die Zugangsdaten. Vor der Bestellung `DIGIKEY_CLIENT_ID`/`DIGIKEY_CLIENT_SECRET` setzen und `tools/pick_digikey.py` laufen lassen. |

Neu hinzugekommen sind außerdem drei Positionen, die keine neue Bestellung
auslösen: D7 teilt sich die Zenerdiode mit D5/D6, R13 und R14 laufen im
10-k-Posten mit. Nur **D8** (1N4148WS, SOD-323) ist ein zusätzlicher Typ.

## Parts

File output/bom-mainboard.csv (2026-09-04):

Menge | Referenzen | Wert | Footprint | MPN | Hersteller | DigiKey | Hinweis | Bestueckung
1 | BT1 | CR1220 | BatteryHolder_Keystone_3000_1x12mm | 3000TR | Keystone Electronics | 36-3000CT-ND | Layout traegt den 12-mm-Halter; CR1220 hat rund ein Viertel der Kapazitaet von CR2032 | ja
2 | C1 C2 | 2u2/100V | C_0805_2012Metric | GRM21BD72A225ME01K | Murata Electronics | 490-GRM21BD72A225ME01KCT-ND |  | ja
1 | C3 | 100n/100V | C_0603_1608Metric | 0603B104K101CT | Walsin Technology Corporation | 1292-1392-1-ND |  | ja
1 | C4 | 2n2/50V | C_0603_1608Metric | C0603C222K5RACTU | KEMET | 399-C0603C222K5RACTUCT-ND |  | ja
1 | C5 | 100p | C_0603_1608Metric | CL10C101JB8NNNC | Samsung Electro-Mechanics | 1276-1008-1-ND |  | ja
2 | C6 C7 | 22u/25V | C_1210_3225Metric | CL32A226MAJNNNE | Samsung Electro-Mechanics | 1276-3373-1-ND |  | ja
14 | C8 C12 C16 C17 C31 C34 C36 C37 C42 C43 C46 C50 C51 C52 | 100n | C_0603_1608Metric | 0603B104K250CT | Walsin Technology Corporation | 1292-1642-1-ND |  | ja
10 | C9 C10 C13 C14 C23 C24 C28 C29 C30 C44 | 1u/16V | C_0603_1608Metric | CL10A105KA8NFNC | Samsung Electro-Mechanics | 1276-1859-1-ND |  | ja
2 | C11 C40 | 22u/10V | C_1210_3225Metric | CL32A226MOJNNNE | Samsung Electro-Mechanics | 1276-1851-1-ND |  | ja
8 | C15 C20 C25 C32 C33 C35 C41 C45 | 10u/10V | C_0805_2012Metric | EMK212ABJ106KG-T | Taiyo Yuden | 587-5837-1-ND |  | ja
4 | C21 C22 C26 C27 | 33p | C_0603_1608Metric | CL10C330JB8NNNC | Samsung Electro-Mechanics | 1276-1070-1-ND |  | ja
1 | D1 | BZX84C15 | SOT-23 | BZX84C15-7-F | Diodes Incorporated | BZX84C15-FDICT-ND | Ersatz fuer BZX84C15LT1G: onsemi-Typ nicht lagernd; Diodes-Typ gleiche Z-Spannung, gleiches SOT-23 | ja
1 | D2 | SMBJ36A | D_SMB | SMBJ36A-13-F | Diodes Incorporated | SMBJ36A-FDICT-ND | unidirektional, Kathode nach +12V | ja
2 | D3 D4 | PMEG3020 | D_SOD-123 | PMEG3020EP,115 | Nexperia USA Inc. | 1727-5836-1-ND | Ersatz fuer PMEG3020EP-115: gleicher Typ, DigiKey schreibt ihn mit Komma | ja
3 | D5 D6 D7 | BZX84C3V3 | SOT-23 | BZX84C3V3LT1G | onsemi | BZX84C3V3LT1GOSCT-ND |  | ja
1 | D8 | 1N4148WS | D_SOD-323 | 1N4148WS-7-F | Diodes Incorporated | 1N4148WS-FDICT-ND |  | ja
4 | D10 D11 D12 D13 | PESD3V3L1BA | D_SOD-123 | SLPESD3V3L1BA | Shenzhen Slkormicro Semicon Co., Ltd. | 5399-SLPESD3V3L1BACT-ND |  | ja
1 | D20 | gruen | LED_0603_1608Metric | LTST-C190GKT | Lite-On Inc. | 160-LTST-C190GKTCT-ND |  | ja
1 | D21 | rot | LED_0603_1608Metric | LTST-C190KRKT | Lite-On Inc. | 160-1436-1-ND |  | ja
1 | D22 | weiss_Sync | LED_0805_2012Metric | LTW-170ZDC | Lite-On Inc. | 160-2220-1-ND |  | ja
1 | F1 | 2A_traege | Fuse_1206_3216Metric | 0453002.MR | Littelfuse Inc. | F3338CT-ND |  | ja
3 | FB2 FB3 FB4 | 600R@100MHz | R_0603_1608Metric | BLM18AG601SN1D | Murata Electronics | 490-1014-1-ND |  | ja
1 | J1 | JST_XH_6pol | JST_XH_S6B-XH-A_1x06_P2.50mm_Horizontal | S6B-XH-A | JST Sales America Inc. | 455-S6B-XH-A-ND | Superseal 1.0 sitzt im Kabelbaum; auf der Platine JST XH | ja
1 | J2 | JST_XH_5pol_MicA | JST_XH_S5B-XH-A_1x05_P2.50mm_Horizontal | S5B-XH-A | JST Sales America Inc. | 455-S5B-XH-A-ND | Superseal 1.0 sitzt im Kabelbaum; auf der Platine JST XH | ja
1 | J3 | JST_XH_5pol_MicB | JST_XH_S5B-XH-A_1x05_P2.50mm_Horizontal | S5B-XH-A | JST Sales America Inc. | 455-S5B-XH-A-ND | Superseal 1.0 sitzt im Kabelbaum; auf der Platine JST XH | ja
1 | J4 | USB-C | USB_C_Receptacle_GCT_USB4085 | USB4085-GF-A | GCT | 2073-USB4085-GF-ACT-ND | durchkontaktiert statt SMD; den XKB-Typ zum vorherigen Footprint fuehrt DigiKey nicht | ja
1 | J5 | microSD_PushPush | microSD_HC_Hirose_DM3D-SF | DM3D-SF | Hirose Electric Co Ltd | HR1941CT-ND |  | ja
1 | J6 | GPS_unbestueckt | PinHeader_1x05_P2.54mm_Vertical | PREC005SAAN-RC | Sullins Connector Solutions | 35-PREC005SAAN-RC-ND |  | ja
1 | J7 | I2C_Erweiterung | PinHeader_1x04_P2.54mm_Vertical | PREC004SAAN-RC | Sullins Connector Solutions | 35-PREC004SAAN-RC-ND |  | ja
1 | L1 | 22u/1A2 | L_Bourns_SRN6045TA | SRN6045TA-220M | Bourns Inc. | SRN6045TA-220MCT-ND |  | ja
2 | L2 L3 | 1mH_CMC | L_CommonMode_Wuerth_WE-SL2 | 744232222 | Würth Elektronik | 732-1474-1-ND |  | ja
1 | LS1 | Piezo_9x9_SMD | Buzzer_Murata_PKMCS0909E | CPT-9019A-SMT-TR | Same Sky (Formerly CUI Devices) | 2223-CPT-9019A-SMT-TRCT-ND | Landmuster aus der Murata-Bibliothek; Murata PKMCS0909E ist abgekuendigt und nur fuer 1,5 V, darum ein 3-V-Typ gleicher Bauform - Landmuster gegen Datenblatt pruefen | ja
1 | Q1 | SI2309CDS | SOT-23 | SI2309CDS-T1-GE3 | Vishay Siliconix | SI2309CDS-T1-GE3CT-ND | Drain am Bordnetz, Source zur Last | Ersatz fuer ZXMP6A17E6TA: ZXMP6A17E6 nicht lagernd und ohnehin SOT-26, der Footprint ist SOT-23; Si2309 60 V / 1,6 A / 345 mOhm passt zum Verpolschutz | ja
2 | Q3 Q4 | 2N7002 | SOT-23 | T2N7002BK,LM | Toshiba Semiconductor and Storage | T2N7002BKLMCT-ND |  | ja
12 | R1 R13 R14 R30 R31 R42 R43 R44 R45 R46 R47 R48 | 10k | R_0603_1608Metric | RC0603FR-0710KL | YAGEO | 311-10.0KHRCT-ND |  | ja
1 | R2 | 680k | R_0603_1608Metric | ERJ-3EKF6803V | Panasonic Industry |  |  | ja
1 | R3 | 150k | R_0603_1608Metric | RC0603FR-07150KL | YAGEO | 311-150KHRCT-ND |  | ja
1 | R4 | 28k7 | R_0603_1608Metric | RMCF0603FT28K7 | Stackpole Electronics Inc | RMCF0603FT28K7CT-ND |  | ja
1 | R5 | 34k0 | R_0603_1608Metric | CRCW060334K0FKEAC | Vishay Dale | 541-5362-1-ND |  | ja
1 | R6 | 12k0 | R_0603_1608Metric | RMCF0603FT12K0 | Stackpole Electronics Inc | RMCF0603FT12K0CT-ND |  | ja
1 | R7 | 0R1 | R_0805_2012Metric | RCWE0805R100FKEA | Vishay Dale | 541-2727-1-ND | Rippelerzeugung Type-2, ggf. am Aufbau nachziehen | ja
3 | R9 R54 R55 | 100k | R_0603_1608Metric | RC0603FR-07100KL | YAGEO | 311-100KHRCT-ND |  | ja
1 | R10 | 47k | R_0603_1608Metric | RC0603FR-0747KL | YAGEO | 311-47.0KHRCT-ND |  | ja
1 | R11 | 470k | R_0603_1608Metric | RC0603FR-07470KL | YAGEO | 311-470KHRCT-ND |  | ja
1 | R12 | 68k | R_0603_1608Metric | RC0603FR-0768KL | YAGEO | 311-68.0KHRCT-ND |  | ja
4 | R20 R21 R22 R23 | 100R | R_0603_1608Metric | CRCW0603100RFKEA | Vishay Dale | 541-100HCT-ND |  | ja
1 | R24 | 33R | R_0603_1608Metric | RC0603FR-0733RL | YAGEO | 13-RC0603FR-0733RLCT-ND |  | ja
2 | R34 R35 | 5k1 | R_0603_1608Metric | RMCF0603FT5K10 | Stackpole Electronics Inc | RMCF0603FT5K10CT-ND |  | ja
2 | R40 R41 | 4k7 | R_0603_1608Metric | RC0603FR-074K7L | YAGEO | 311-4.70KHRCT-ND |  | ja
1 | R49 | 120R | R_0805_2012Metric | RMCF0805FT120R | Stackpole Electronics Inc | 738-RMCF0805FT120RCT-ND |  | nur wenn Endknoten
3 | R50 R51 R52 | 1k | R_0603_1608Metric | CRCW06031K00FKEA | Vishay Dale | 541-1.00KHCT-ND |  | ja
1 | R53 | 18R | R_0805_2012Metric | RK73H2ATTD18R0F | KOA Speer Electronics, Inc. | 2019-RK73H2ATTD18R0FCT-ND |  | ja
1 | SW1 | RESET | SW_SPST_TL3342 | TL3342F260QG | E-Switch | EG5470CT-ND |  | ja
1 | SW2 | BOOT | SW_SPST_TL3342 | TL3342F260QG | E-Switch | EG5470CT-ND |  | ja
1 | SW3 | REC | SW_SPST_TL3342 | TL3342F260QG | E-Switch | EG5470CT-ND |  | ja
1 | SW4 | MARK | SW_SPST_TL3342 | TL3342F260QG | E-Switch | EG5470CT-ND |  | ja
1 | TP1 | UART0_TX | TestPoint_Pad_D1.5mm |  |  |  |  | ja
1 | TP2 | UART0_RX | TestPoint_Pad_D1.5mm |  |  |  |  | ja
1 | U1 | LM5164DDA | SOIC-8-1EP_3.9x4.9mm_P1.27mm_EP2.29x3mm | LM5164DDAT | Texas Instruments | 296-53428-1-ND | Ersatz fuer LM5164DDAR: gleicher Baustein, nur kleinere Rolle - die grosse Rolle ist leer | ja
1 | U2 | NCP1117ST33 | SOT-223-3_TabPin2 | NCP1117ST33T3G | onsemi | NCP1117ST33T3GOSCT-ND | Ersatz fuer TLV1117LV33DCYR: TLV1117LV komplett leer; NCP1117 SOT-223, gleiche Belegung, 1 A, Abfall 1,2 V bei 4,6 V Eingang noch ausreichend | ja
1 | U3 | LP5907MFX-3.3 | SOT-23-5 | LP5907MFX-3.3/NOPB | Texas Instruments | 296-38557-1-ND | Ersatz fuer TPS7A2033PDBVR: TPS7A2033 in SOT-23-5 leer; LP5907 gleiche Belegung, 6,5 uVrms Rauschen - passt zur Analogversorgung des ADC | ja
1 | U5 | PCM1863DBT | TSSOP-30_4.4x7.8mm_P0.5mm | PCM1863QDBTRQ1 | Texas Instruments | 296-50383-1-ND | Ersatz fuer PCM1863DBTR: die Standardversion ist leer; gleicher Baustein in Automotive-Qualifizierung, gleiches 30-TSSOP - auf einem Motorrad ohnehin die passendere Wahl | ja
1 | U6 | ESP32-S3-WROOM-1-N8R2 | ESP32-S3-WROOM-1 | ESP32-S3-WROOM-1-N8R2 | Espressif Systems | 5407-ESP32-S3-WROOM-1-N8R2CT-ND |  | ja
1 | U7 | DS3231SN | SOIC-16W_7.5x10.3mm_P1.27mm | DS3231SN# | Analog Devices Inc./Maxim Integrated | DS3231SN#-ND |  | ja
1 | U8 | SN65HVD230Q | SOIC-8_3.9x4.9mm_P1.27mm | SN65HVD230QDG4Q1 | Texas Instruments | 296-23353-5-ND | Ersatz fuer SN65HVD230DR: gleicher Baustein in Automotive-Qualifizierung, mit Flankensteuerung an Rs wie im Schaltplan | optional
1 | Y1 | 24.576MHz | Oscillator_SMD_Abracon_ASE-4Pin_3.2x2.5mm | ASEMB-24.576MHZ-LC-T | Abracon LLC | 535-11749-1-ND | Ersatz fuer ASE-24.576MHZ-ET: ASE-Reihe leer; ASEMB gleiches Gehaeuse 3,2 x 2,5 mm, gleiche Belegung, 1,8-3,3 V | ja

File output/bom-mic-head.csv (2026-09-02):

Menge | Referenzen | Wert | Footprint | MPN | Hersteller | DigiKey | Hinweis | Bestueckung
2 | C1 C4 | 10u/16V | C_0805_2012Metric | GRM21BR61E106MA73L | Murata Electronics | 490-10748-1-ND |  | ja
2 | C3 C7 | 1u/16V | C_0603_1608Metric | CL10A105KA8NFNC | Samsung Electro-Mechanics | 1276-1859-1-ND |  | ja
2 | C5 C6 | 100n | C_0603_1608Metric | 0603B104K250CT | Walsin Technology Corporation | 1292-1642-1-ND |  | ja
1 | FB1 | 600R@100MHz | R_0603_1608Metric | BLM18AG601SN1D | Murata Electronics | 490-1014-1-ND |  | ja
1 | J1 | Loetpads_Kabel_5x | SolderWire-0.1sqmm_1x05_2reihig_P2.6mm | - |  |  |  | ja
1 | MK1 | IM73A135V01 | Infineon_PG-LLGA-5-1 | IM73A135V01XTSA1 |  |  |  | ja
2 | R1 R2 | 100R | R_0603_1608Metric | CRCW0603100RFKEA | Vishay Dale | 541-100HCT-ND |  | ja
1 | R3 | 47k | R_0603_1608Metric | RC0603FR-0747KL | YAGEO | 311-47.0KHRCT-ND |  | ja
1 | U1 | LP5907MFX-2.8 | SOT-23-5 | LP5907MFX-2.8/NOPB | Texas Instruments | 296-39063-1-ND | Ersatz fuer TPS7A2028PDBVR: TPS7A2028 leer; LP5907 gleiche Belegung in SOT-23-5, 2,8 V, 6,5 uVrms - passt zur Mikrofonversorgung | ja
1 | U2 | OPA2325 | SOIC-8_3.9x4.9mm_P1.27mm | OPA2325ID | Texas Instruments | 296-45120-5-ND | Ersatz fuer OPA2325AIDR: die Nummer im Schaltplan gibt es nicht; OPA2325ID ist der SOIC-8-Typ, nur 16 Stueck am Lager | ja

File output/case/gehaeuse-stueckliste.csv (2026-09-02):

Bezeichnung | Menge | MPN | Hersteller | DigiKey | Bestand | Preis | Hinweis
Kabelverschraubung M8x1,5, Kabel 2..5 mm | 2 | CG-P-M8-1.25 | Adam Tech | 2057-CG-P-M8-1.25-ND | 4549 | 0.70 | Hauptgehaeuse, Mikrofonkabel A und B. Gewindelaenge >= 6 mm fuer 5 mm Wand
Kabelverschraubung M12x1,5, Kabel 3..6,5 mm | 1 | AIO-CSM12 | Amphenol Industrial Operations | AIO-CSM12-ND | 28817 | 1.87 | Hauptgehaeuse, Bordnetzstrang
Gewindeeinsatz M3 zum Einschmelzen | 8 |  |  |  |  |  | 6 x Deckel, 2 x Serviceklappe. Laenge <= 5 mm, sonst bricht der Einsatz an der Klappe in den Hohlraum durch | kein lagernder Treffer, Begriff verfeinern
Gewindeeinsatz M2,5 zum Einschmelzen | 4 |  |  |  |  |  | Platinensockel im Hauptgehaeuse | kein lagernder Treffer, Begriff verfeinern
Zylinderschraube M3x10, Innensechskant | 6 |  |  |  |  |  | Deckel. Normteil, Baumarkt oder Schraubenhandel
Zylinderschraube M3x8, Innensechskant | 2 |  |  |  |  |  | Serviceklappe
Zylinderschraube M2,5x6 | 4 |  |  |  |  |  | Platine im Hauptgehaeuse
Blechschraube M2x8 oder Schraube M2x10 | 8 |  |  |  |  |  | Mikrofonkoepfe, 4 je Kopf
Rundschnur NBR d2,0 mm | 300 |  |  |  |  |  | Hauptgehaeusedichtung, rund 290 mm Umfang. Ablaengen und stumpf kleben - fuer diesen Umfang gibt es keinen O-Ring von der Stange | kein lagernder Treffer, Begriff verfeinern
Rundschnur NBR d1,5 mm | 120 |  |  |  |  |  | Serviceklappe, rund 110 mm Umfang
Kabelbinder 2,5 mm breit | 2 |  |  |  |  |  | Zugentlastung an den Mikrofonkoepfen
Vergussmasse, 2-Komponenten | 1 |  |  |  |  |  | Mikrofonkoepfe. Schallbohrung und Dichtsockel freihalten

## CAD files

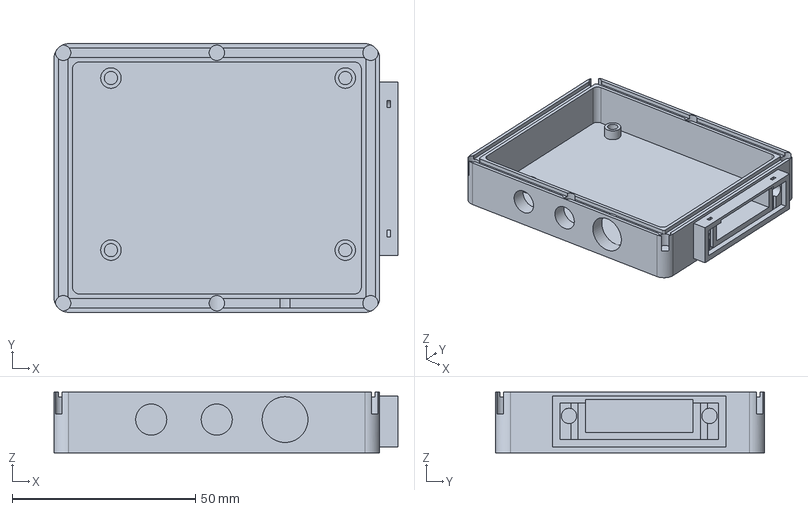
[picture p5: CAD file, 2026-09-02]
output/case/hauptgehaeuse-unterschale.step
94.0 x 73.4 x 16.6 mm

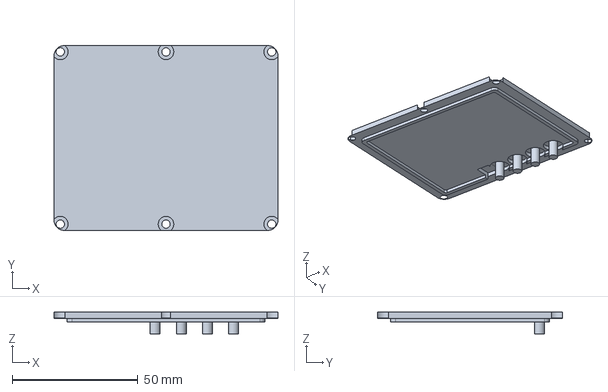
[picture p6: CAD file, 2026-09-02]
output/case/hauptgehaeuse-deckel.step
89.0 x 73.4 x 8.70 mm

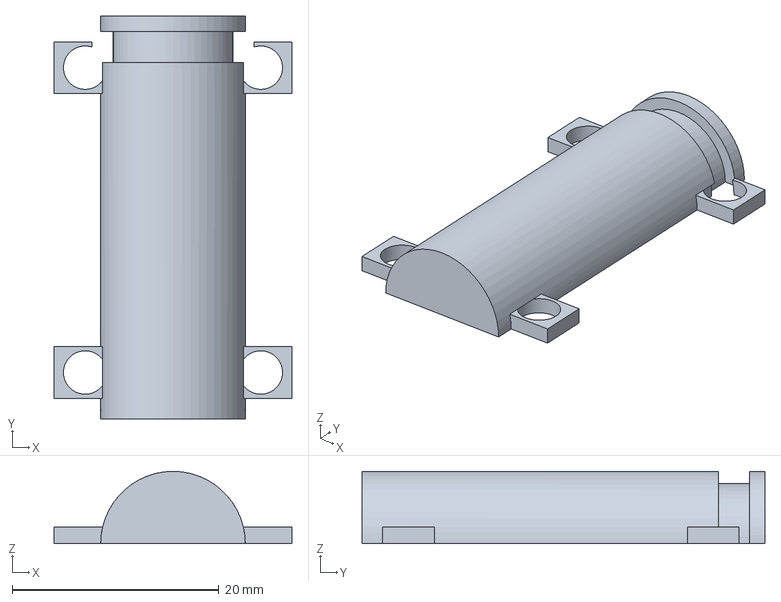
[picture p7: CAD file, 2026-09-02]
output/case/mikrofonkopf-oberschale.step
23.0 x 39.0 x 7.00 mm

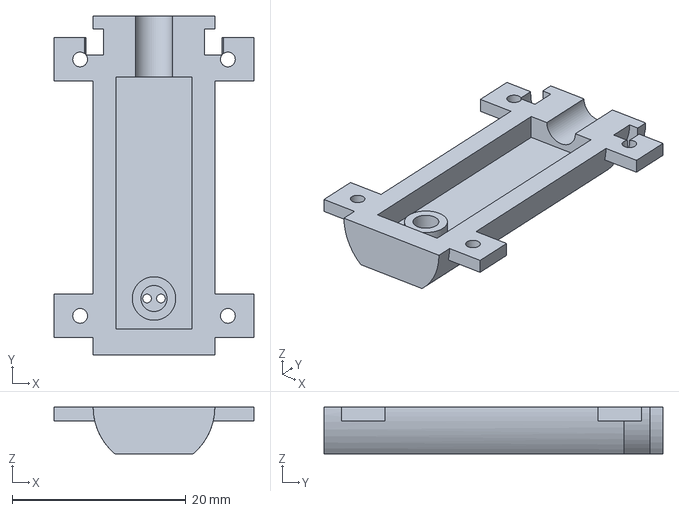
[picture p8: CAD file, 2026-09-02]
output/case/mikrofonkopf-unterschale.step
23.0 x 39.0 x 5.35 mm

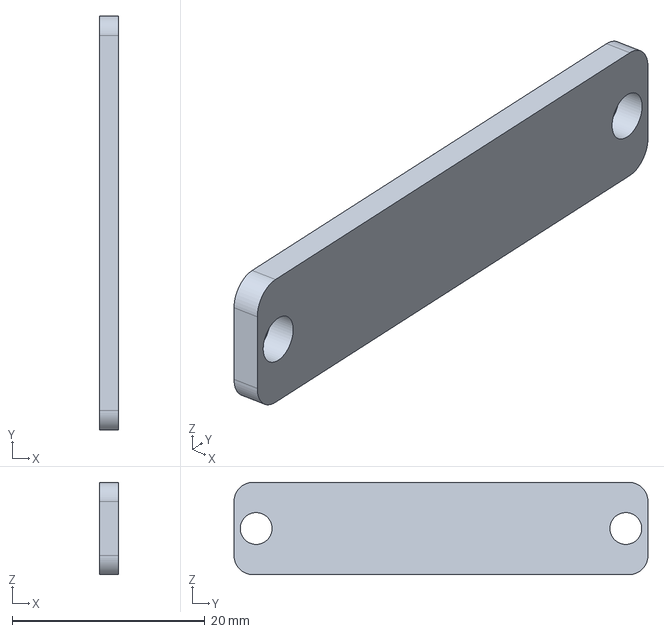
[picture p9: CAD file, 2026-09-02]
output/case/hauptgehaeuse-serviceklappe.step
2.00 x 43.0 x 9.60 mm

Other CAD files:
output/case/hauptgehaeuse-deckel.stl
output/case/hauptgehaeuse-serviceklappe.stl
output/case/hauptgehaeuse-unterschale.stl
output/case/mikrofonkopf-oberschale.stl
output/case/mikrofonkopf-unterschale.stl

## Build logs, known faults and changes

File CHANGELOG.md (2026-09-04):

# Änderungen

Alle nennenswerten Änderungen an diesem Projekt stehen hier.
Das Format folgt [Keep a Changelog](https://keepachangelog.com/de/1.1.0/),
die Versionierung [Semantic Versioning](https://semver.org/lang/de/).

## [0.1.0] — 2026-09-04

Erste Veröffentlichung. Schaltplan, Layout, Gehäuse und Firmware sind
vollständig, **auf Hardware gelaufen ist davon nichts** — es gibt noch
keinen Aufbau.

### Hardware

- Hauptplatine, 72 × 55 mm, vier Lagen, beidseitig bestückt, 131 Bauteile.
  Sechs Schaltplanblätter: Versorgung, Analogteil, Wandler, Rechner, Ein-
  und Ausgabe.
- Mikrofonkopf, 8 × 27 mm, zwei Lagen, 14 Bauteile, zweimal identisch
  aufzubauen. Eigenes KiCad-Projekt unter `mic-head/`.
- Zwei differentielle Kanäle mit 135 dBSPL Grenzschalldruck: IM73A135 auf
  OPA2325 als Impedanzwandler, 2,8-V-LDO im Kopf, vier Meter geschirmtes
  Twisted Pair zur Hauptplatine, dort Gleichtaktdrossel und Klemmdioden.
- PCM1863 als Wandler, 24 Bit bei 48 kHz, 110 dB Störabstand, Taktherr an
  einem eigenen 24,576-MHz-Oszillator; der ESP32-S3 empfängt nur.
- ESP32-S3-WROOM-1-N8R2 mit microSD-Karte, DS3231-TCXO (±2 ppm) als
  Zeitbasis, CAN über SN65HVD230.
- Versorgung aus dem 12-V-Bordnetz über einen LM5164-Abwärtswandler mit
  Verpolschutz.
- **Zündungserkennung.** Die Freigabe des Wandlers hängt an Klemme 15, die
  Versorgung an Klemme 30. Zündung aus schaltet nicht sofort stromlos: der
  ESP32 hält seine eigene Versorgung über `PWR_HOLD` und D8 fest, schließt
  die Datei und lässt dann los. Ruhestrom rechnerisch 30 µA statt der rund
  100 mA einer dauernd laufenden Platine.
- Gehäuse aus fünf gedruckten Teilen mit Rundschnurdichtung, parametrisch
  aus den Platinendateien erzeugt. Kopf A sitzt am Endrohr — das Mikrofon
  ist auf 85 °C begrenzt, deshalb ASA aufwärts.
- Alle Kabelstecker an der oberen Kante nach außen, USB-C und microSD
  rechts hinter einer gemeinsamen Serviceklappe, Leuchtdioden und Taster
  unten. Aufbauhöhe 11,9 mm, auf der Rückseite steht nichts über 2,7 mm.

### Firmware

ESP-IDF 5.3.2, Ziel `esp32s3`, baut warnungsfrei, 664 kB Abbild.

- F1 I2S-Slave-Empfang per DMA (`audio.c`)
- F2 vorallokierte Datei, Kopf beim Schließen gepatcht (`speicher.c`)
- F3 BWF/BEXT-Zeitstempel aus der RTC (`speicher.c`)
- F4 1-Hz-Anker latcht den Samplezähler (`zeitbasis.c`) — driftfreie
  Zuordnung Wanduhrzeit ↔ Sample über die ganze Aufnahme
- F5 PCM1863 über I²C, differentiell, Taktherr (`pcm1863.c`)
- F6 Übersteuerungsanzeige (`bedienung.c`)
- F7 Zündungsautomat mit sauberem Herunterfahren (`zuendung.c`)
- F8 Sync-Marker aus Blitz und Piep samt Samplenummer (`bedienung.c`)
- GoPro-Kopplung über Bluetooth LE nach der Open-GoPro-Schnittstelle
  (`gopro.c`): Video starten heißt Aufnahme starten, der Taster am Gerät
  löst umgekehrt die Kamera aus.
- **Der Motor ist der dritte Auslöser** neben Taster und Kamera: springt er
  an, hebt die Lichtmaschine das Bordnetz über 13,2 V.
- `pins.h` wird aus der Netzliste erzeugt, nicht abgetippt
  (`firmware/tools/pins_aus_netzliste.py`).

### Fertigungsunterlagen

Unter `output/`: Gerber-Pakete beider Platinen, Positionsdateien,
Stücklisten, Schaltplan- und Layout-PDF, Bilder. 71 von 76
Beschaffungspositionen tragen eine bei DigiKey lagernde Herstellernummer.

### Geprüft

DRC, ERC, Schaltplanparität, eine eigene Abnahme und der Übersetzungslauf
der Firmware.

| | Mikrofonkopf | Hauptplatine |
|---|---|---|
| Offene Verbindungen | 0 | 8 |
| DRC-Fehler | 0 | 0 |
| ERC-Fehler | 0 | 0 |
| Schaltplanparität | 0 | 6 |

### Bekannte Einschränkungen

- **Kein Aufbau, keine Messung.** Alles hier ist gerechnet, geprüft und
  übersetzt — nichts ist gelötet.
- Auf der Hauptplatine bleiben **acht Verbindungen offen**, allesamt Stücke
  der Masseflächen, kein Pad und kein Signalnetz. Vor der Fertigung im
  interaktiven Router zu schließen.
- **R2 (680 k)** hat beim Umbau auf die Zündungsfreigabe seinen Wert
  gewechselt und trägt noch keine geprüfte Bestellnummer.
- MK1, das IM73A135V01XTSA1, ist aktiv, bei DigiKey aber ohne Bestand;
  andere Distributoren führen es.
- Die sechs Abweichungen der Schaltplanparität sind die vier
  Befestigungsbohrungen ohne Symbol und die Schirmanschlüsse von USB-C und
  Kartenhalter, die der Footprint führt und das Symbol nicht.
- Offen aus der Spezifikation: F6 automatische Pegelabsenkung, F9 WLAN und
  NTP, F10 CAN in die Begleitdatei, F11 Download über USB-MSC oder WLAN.
- Die Platine kann der Kamera **keinen Ton liefern**. Der ESP32-S3
  beherrscht nur Bluetooth LE, GoPro nimmt drahtlosen Ton über HFP an —
  ein Bluetooth-Classic-Profil, und einkanalig mit 8 oder 16 kHz.
- Die Generatorskripte (`tools/`, `case/`) liegen nicht im Repository. Die
  Dateien auf der Platte sind weiter als die Generatoren; ein Neulauf würde
  Beschaffungsfelder, korrigierte Landmuster, zwei reparierte Symbole und
  fünf PWR_FLAG überschreiben. Siehe `docs/entwicklung.md`.

[0.1.0]: https://github.com/HasiKe/Exhaust-Mic/releases/tag/v0.1.0

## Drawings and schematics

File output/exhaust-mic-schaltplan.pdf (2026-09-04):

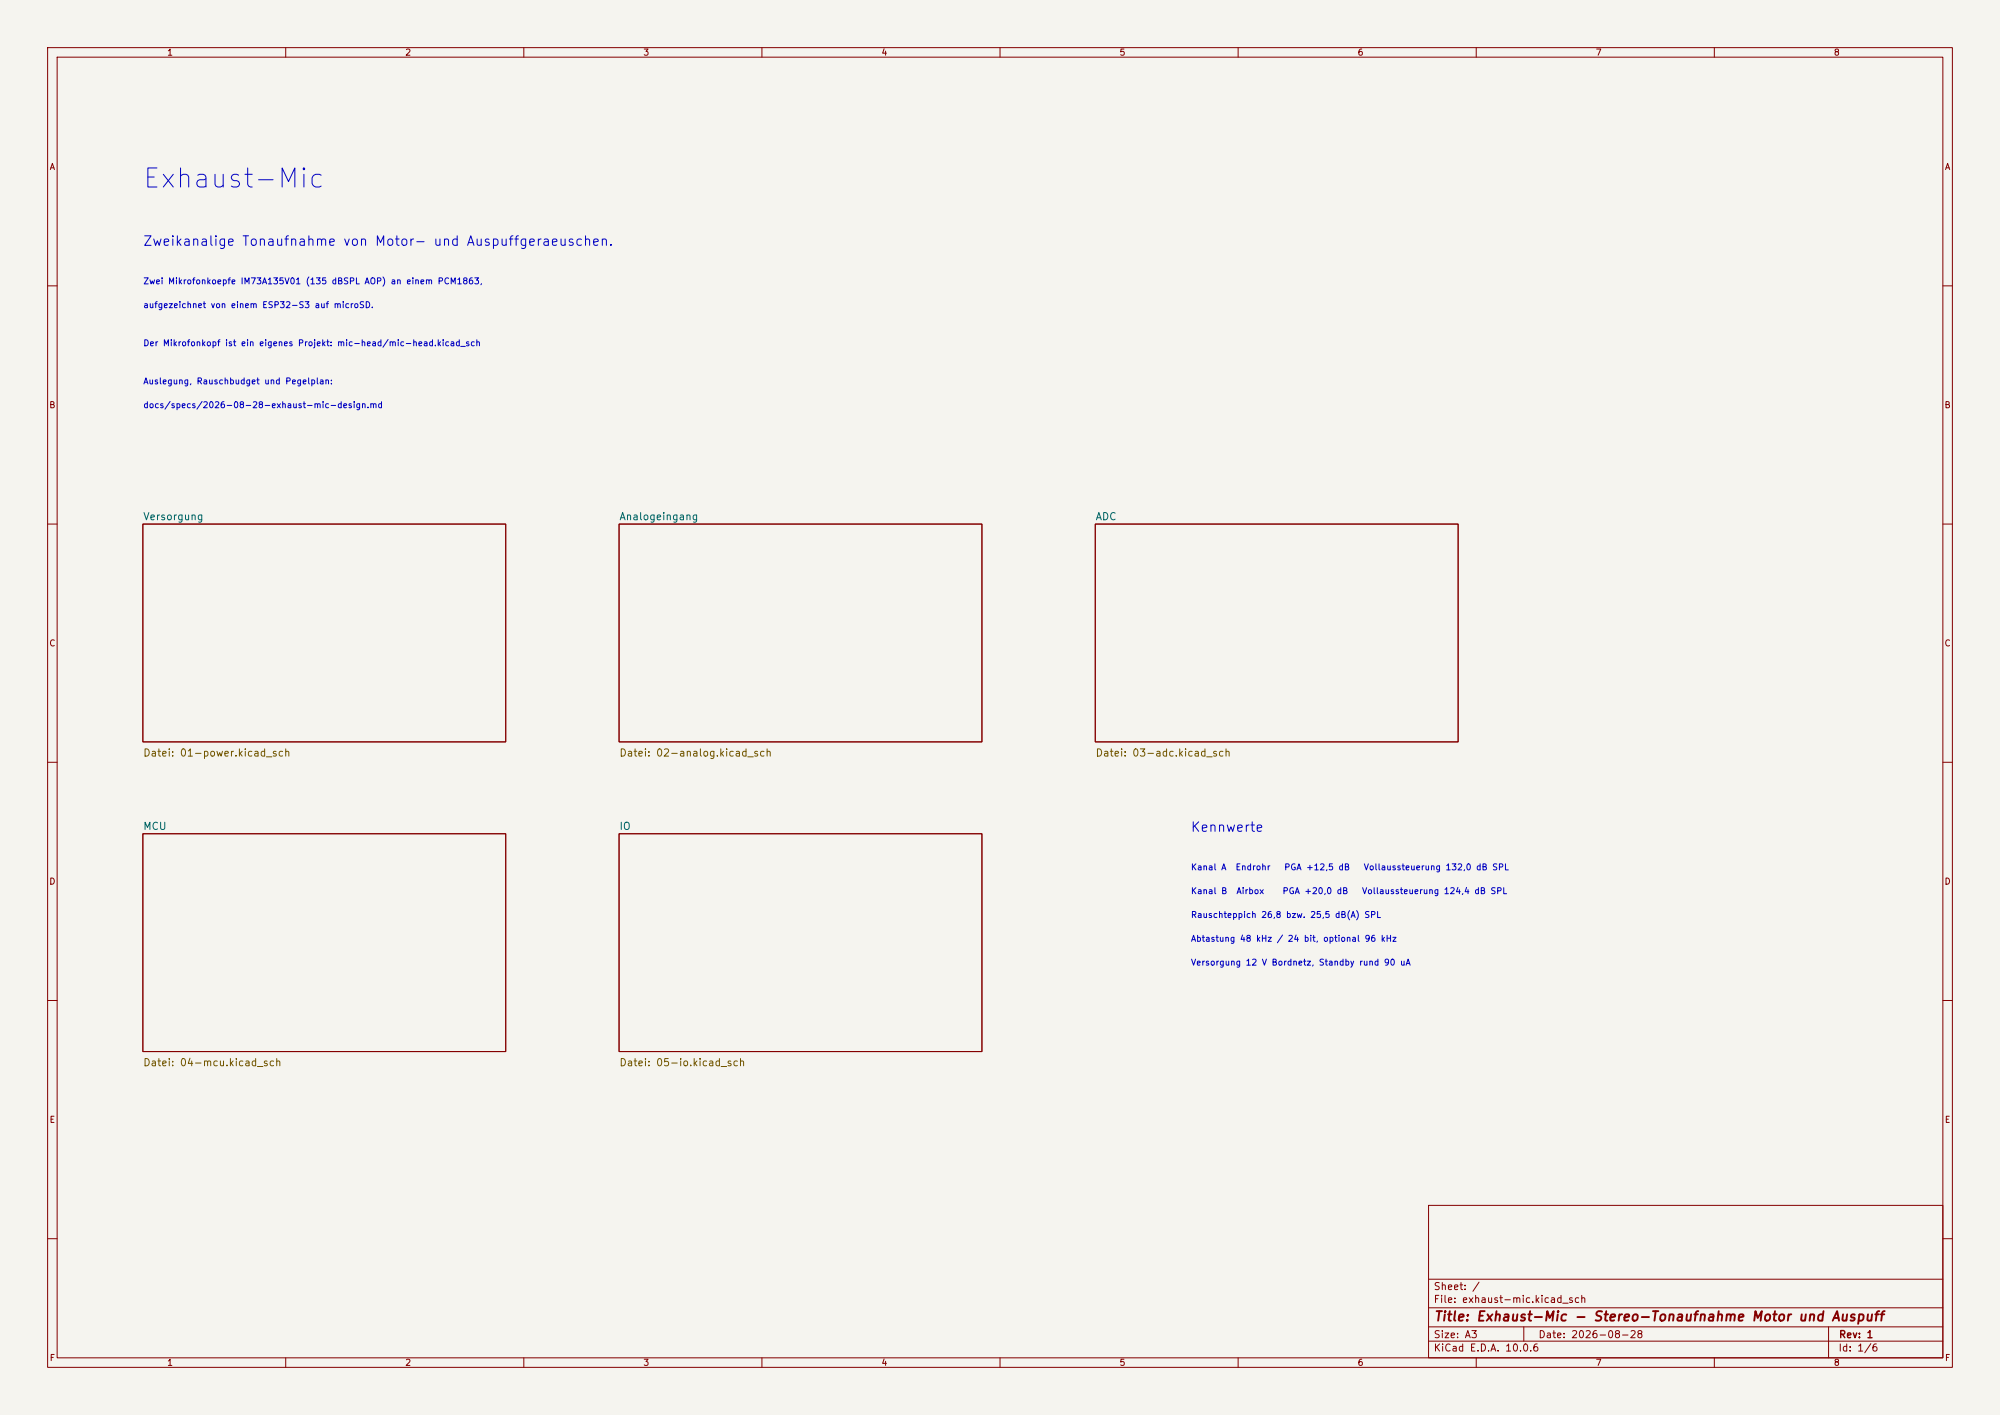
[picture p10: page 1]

Rauschteppich 26,8 bzw. 25,5 dB(A) SPL Exhaust-Mic

Zweikanalige Tonaufnahme von Motor- und Auspuffgeraeuschen. Der Mikrofonkopf ist ein eigenes Projekt: mic-head/mic-head.kicad_sch

aufgezeichnet von einem ESP32-S3 auf microSD. Zwei Mikrofonkoepfe IM73A135V01 (135 dBSPL AOP) an einem PCM1863,

Auslegung, Rauschbudget und Pegelplan:

docs/specs/2026-08-28-exhaust-mic-design.md

Versorgung 12 V Bordnetz, Standby rund 90 uA

Sheet: /
File: exhaust-mic.kicad_sch
Title: Exhaust-Mic - Stereo-Tonaufnahme Motor und Auspuff

Size: A3 | Rev: 1 | F Date: 2026-08-28
KiCad E.D.A. 10.0.6 | Id: 1/6

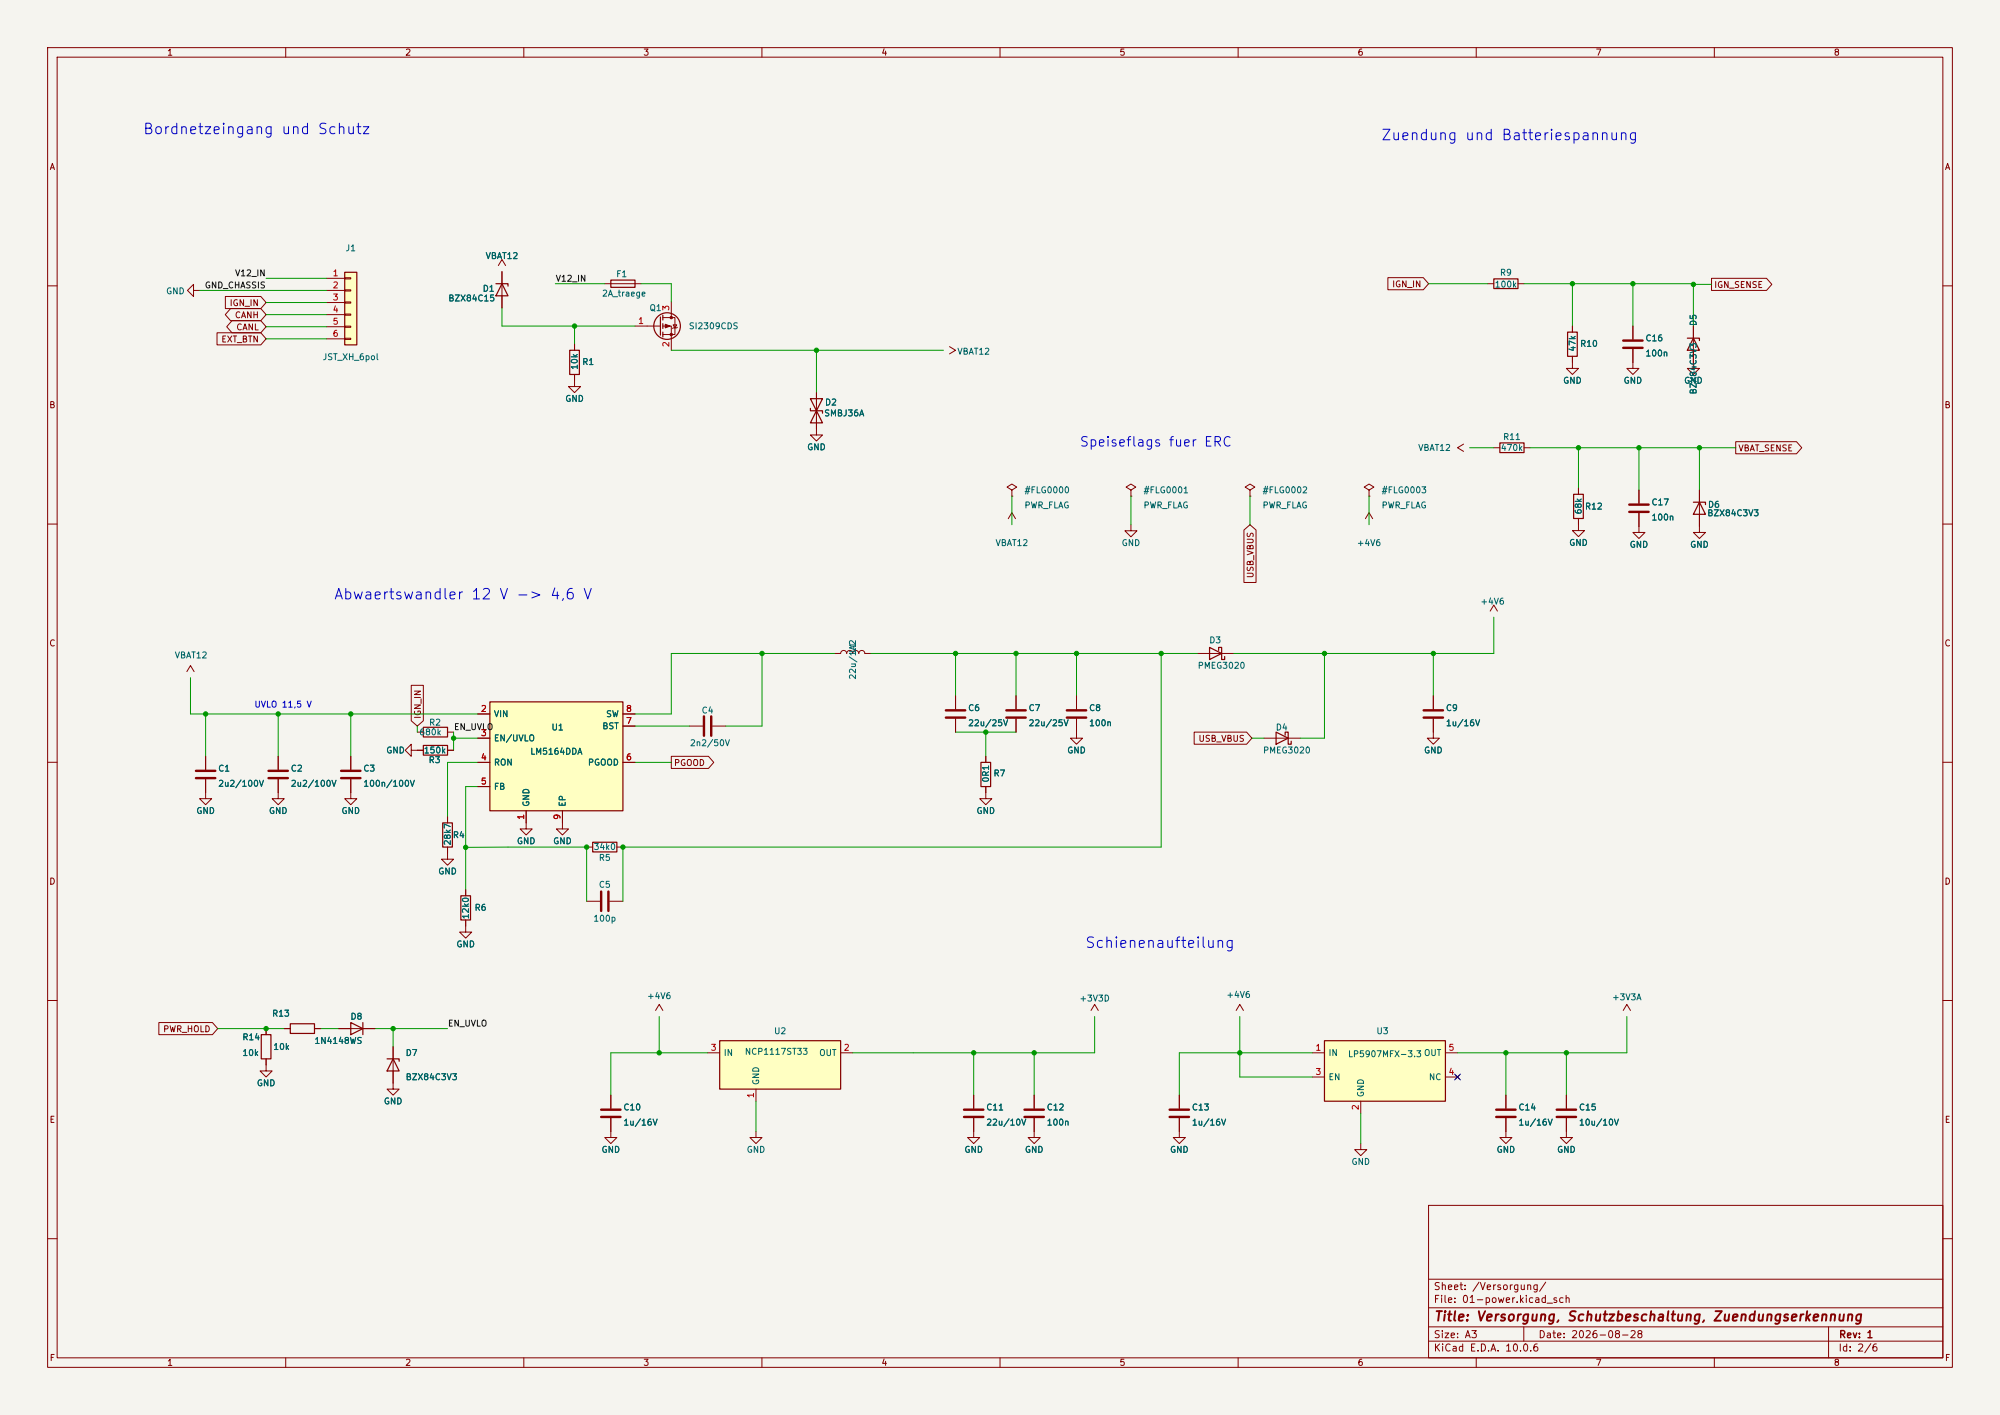
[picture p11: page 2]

Sheet: /Versorgung/
File: 01-power.kicad_sch
Title: Versorgung, Schutzbeschaltung, Zuendungserkennung

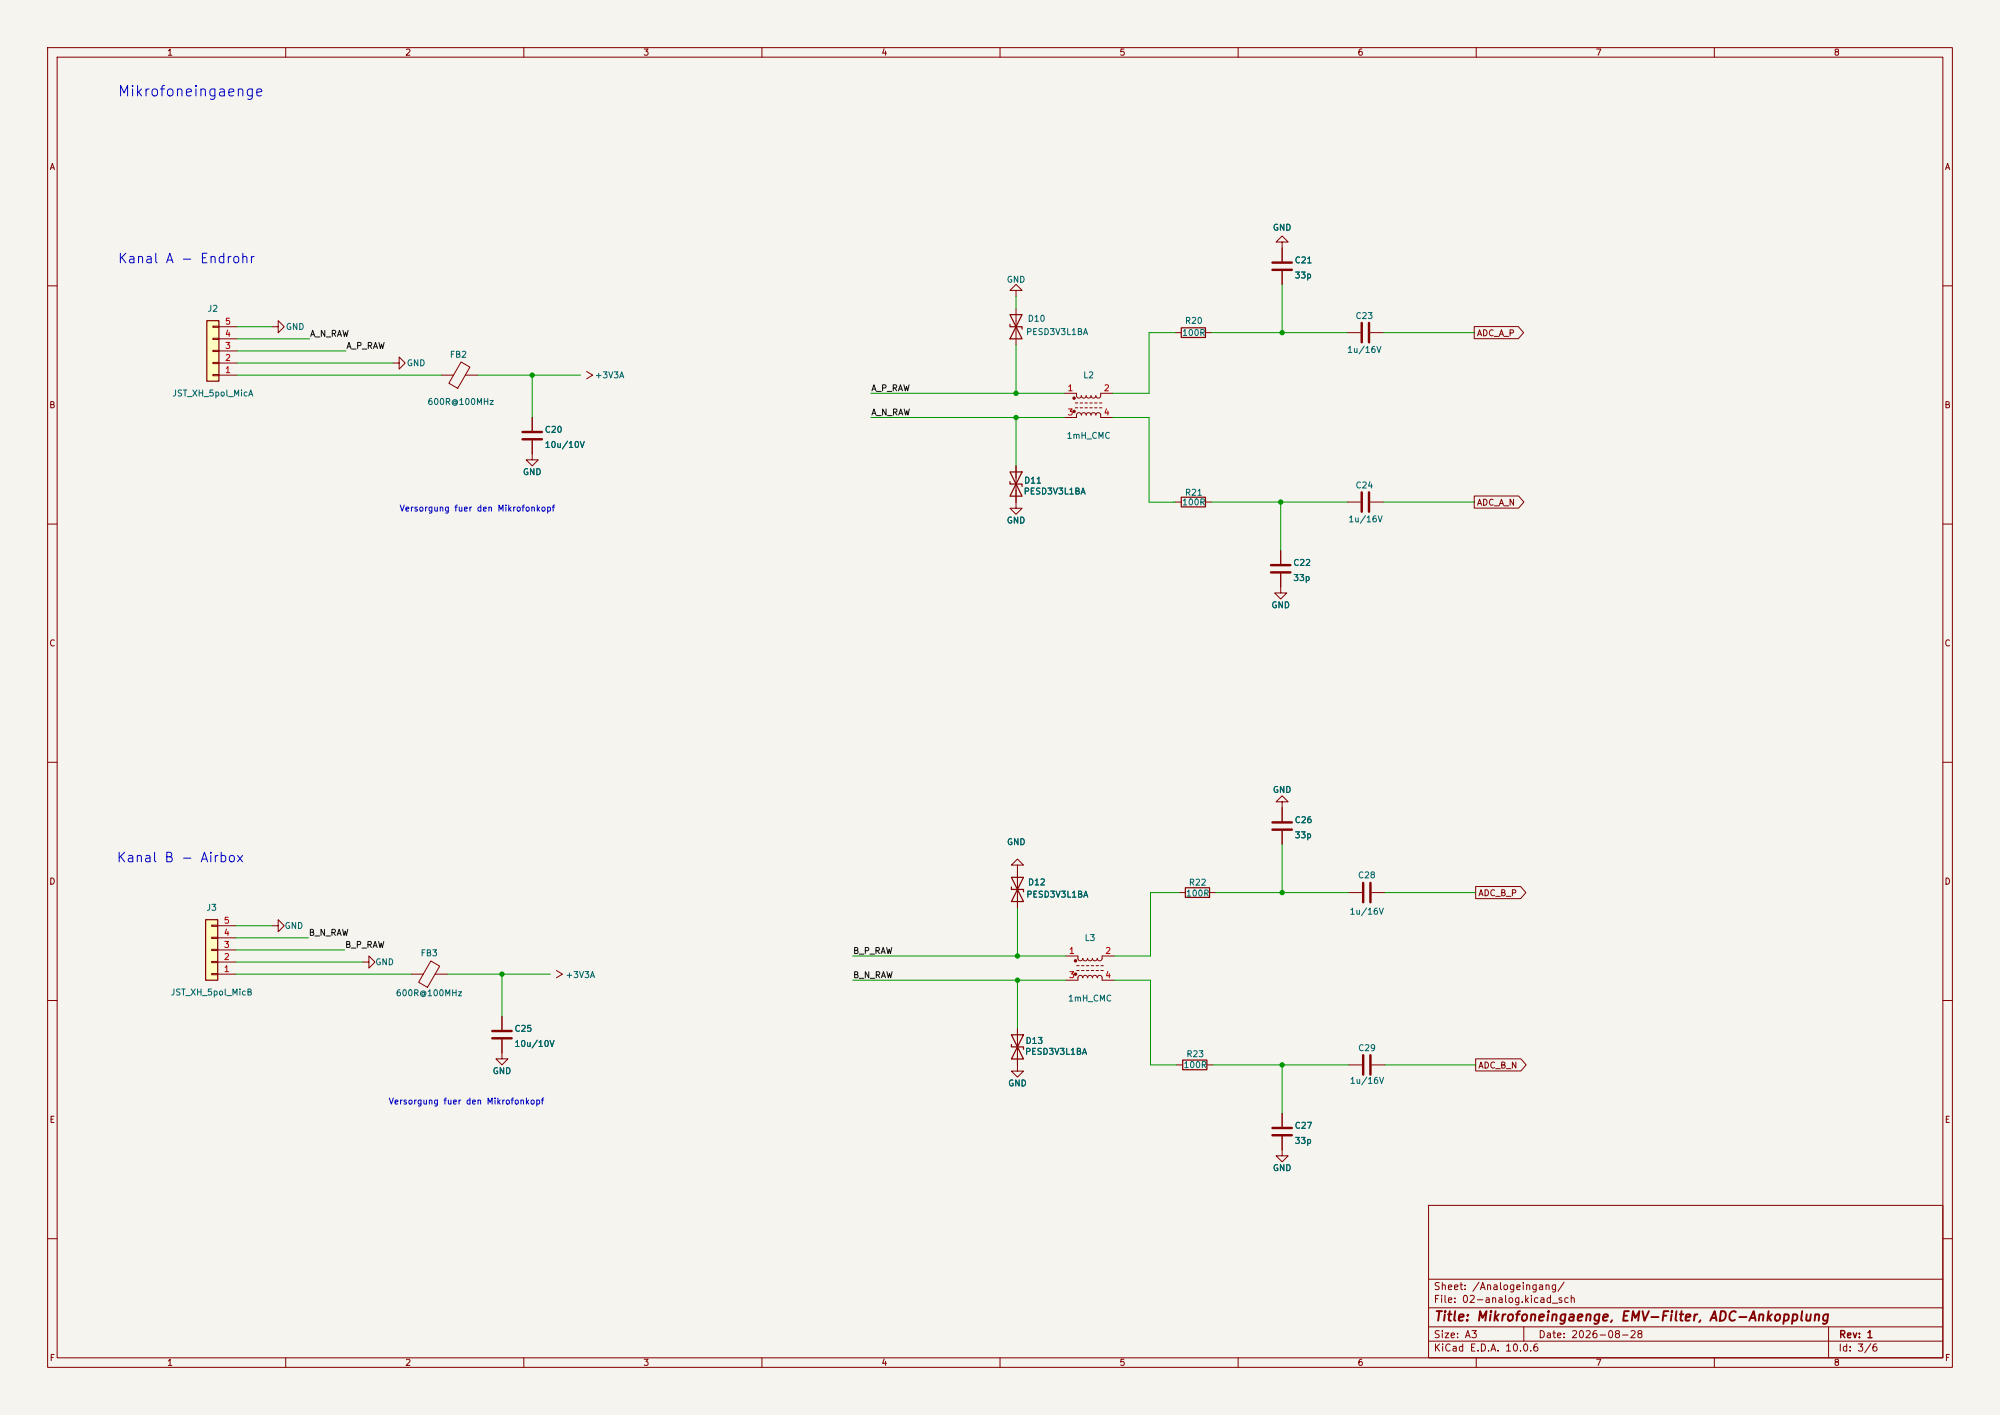
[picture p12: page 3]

Versorgung fuer den Mikrofonkopf

Sheet: /Analogeingang/
File: 02-analog.kicad_sch
Title: Mikrofoneingaenge, EMV-Filter, ADC-Ankopplung

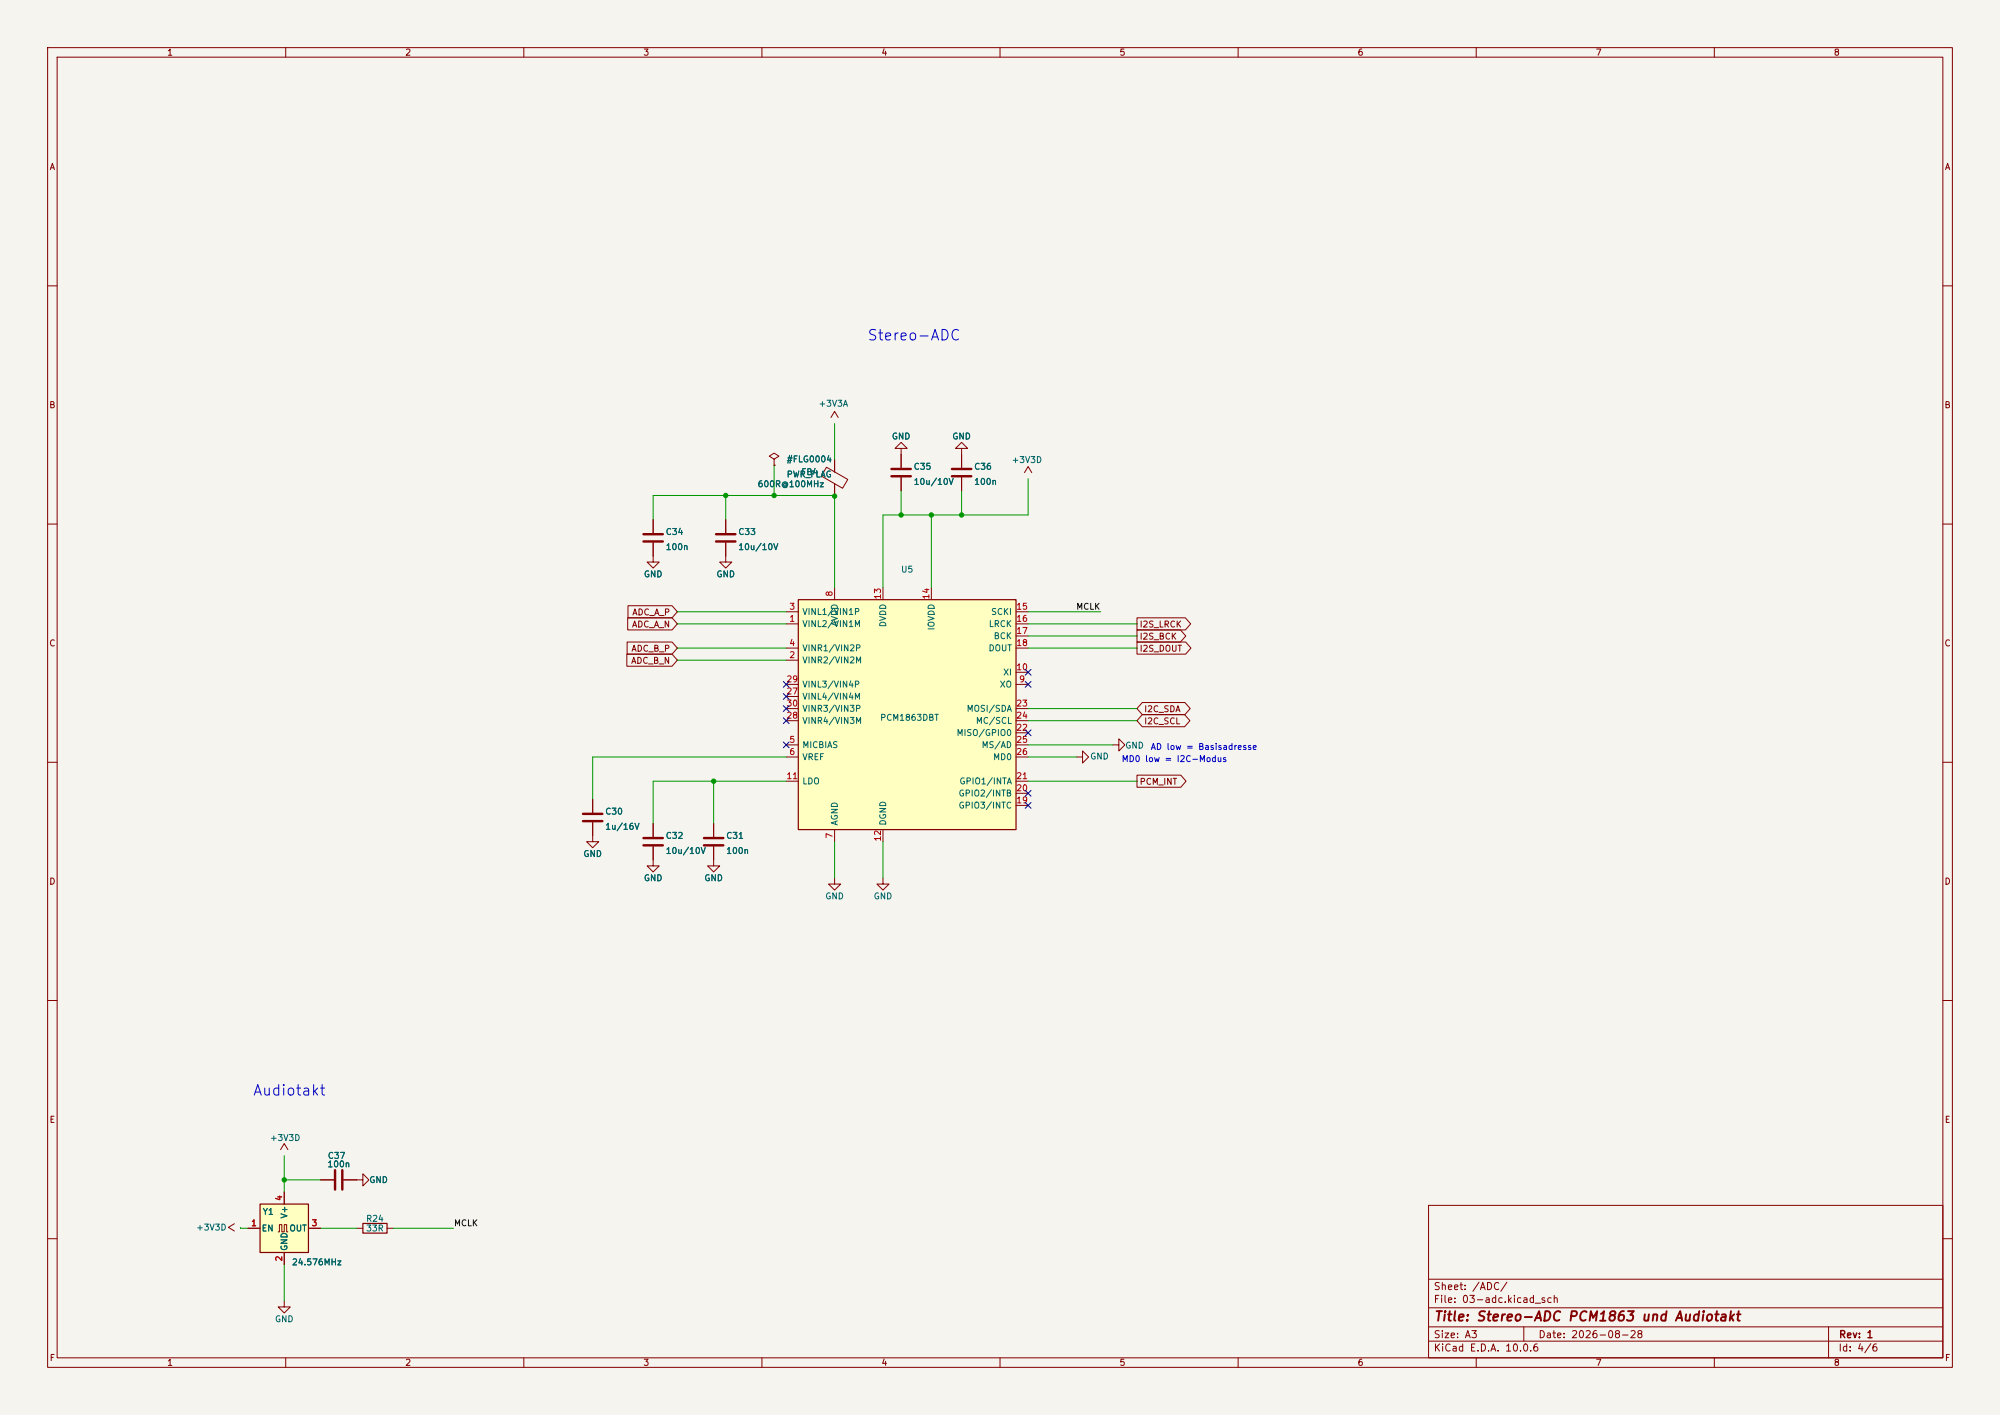
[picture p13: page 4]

AD low = Basisadresse Audiotakt

Sheet: /ADC/
File: 03-adc.kicad_sch
Title: Stereo-ADC PCM1863 und Audiotakt

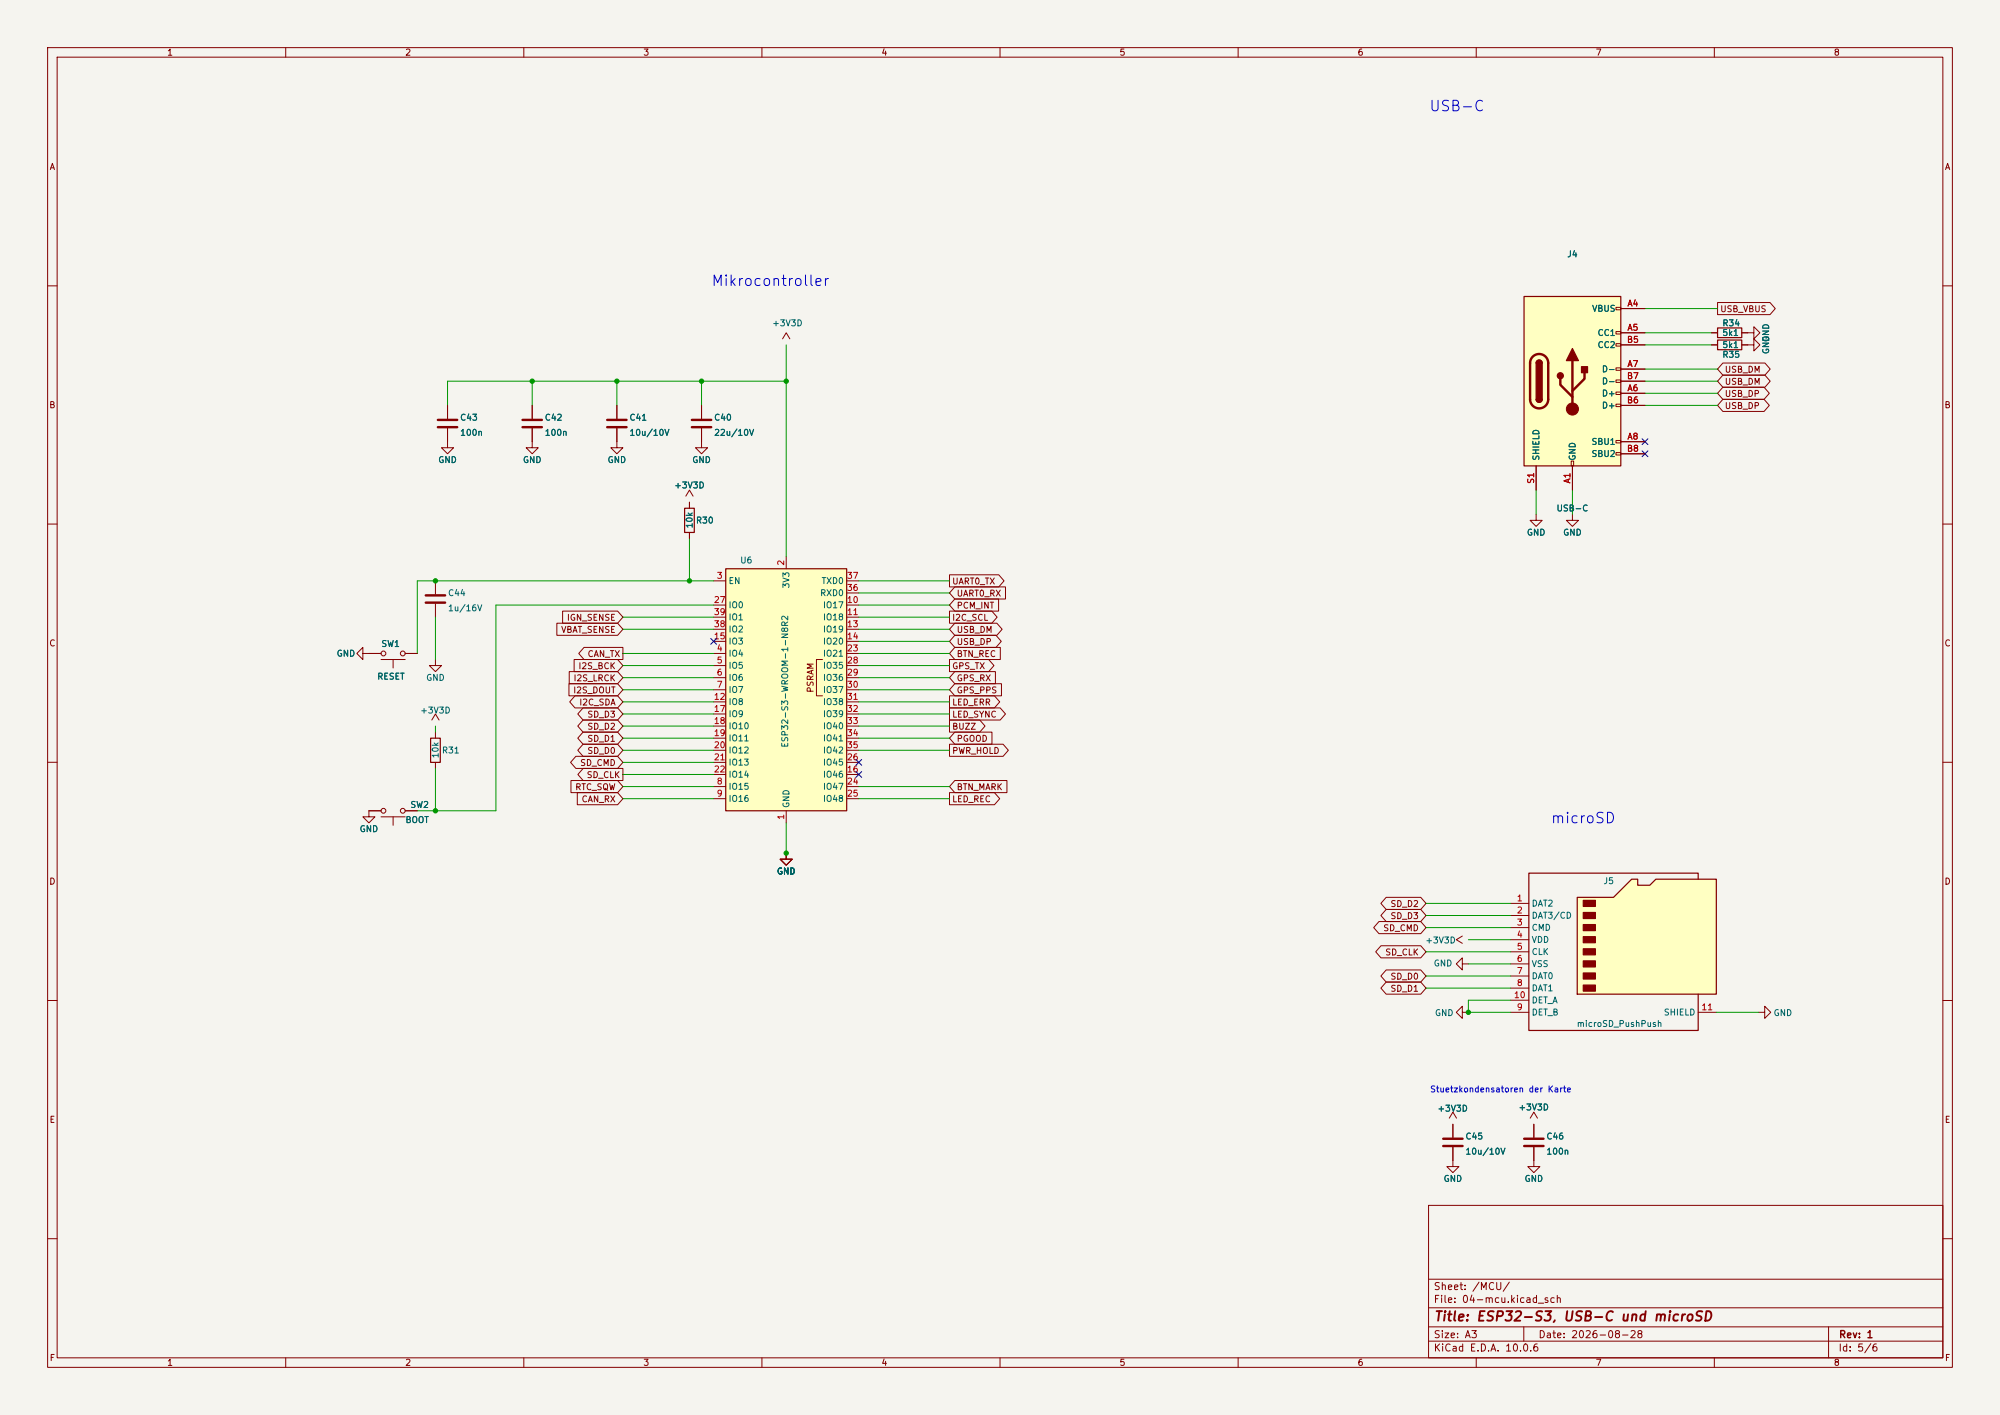
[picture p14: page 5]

Sheet: /MCU/
File: 04-mcu.kicad_sch
Title: ESP32-S3, USB-C und microSD

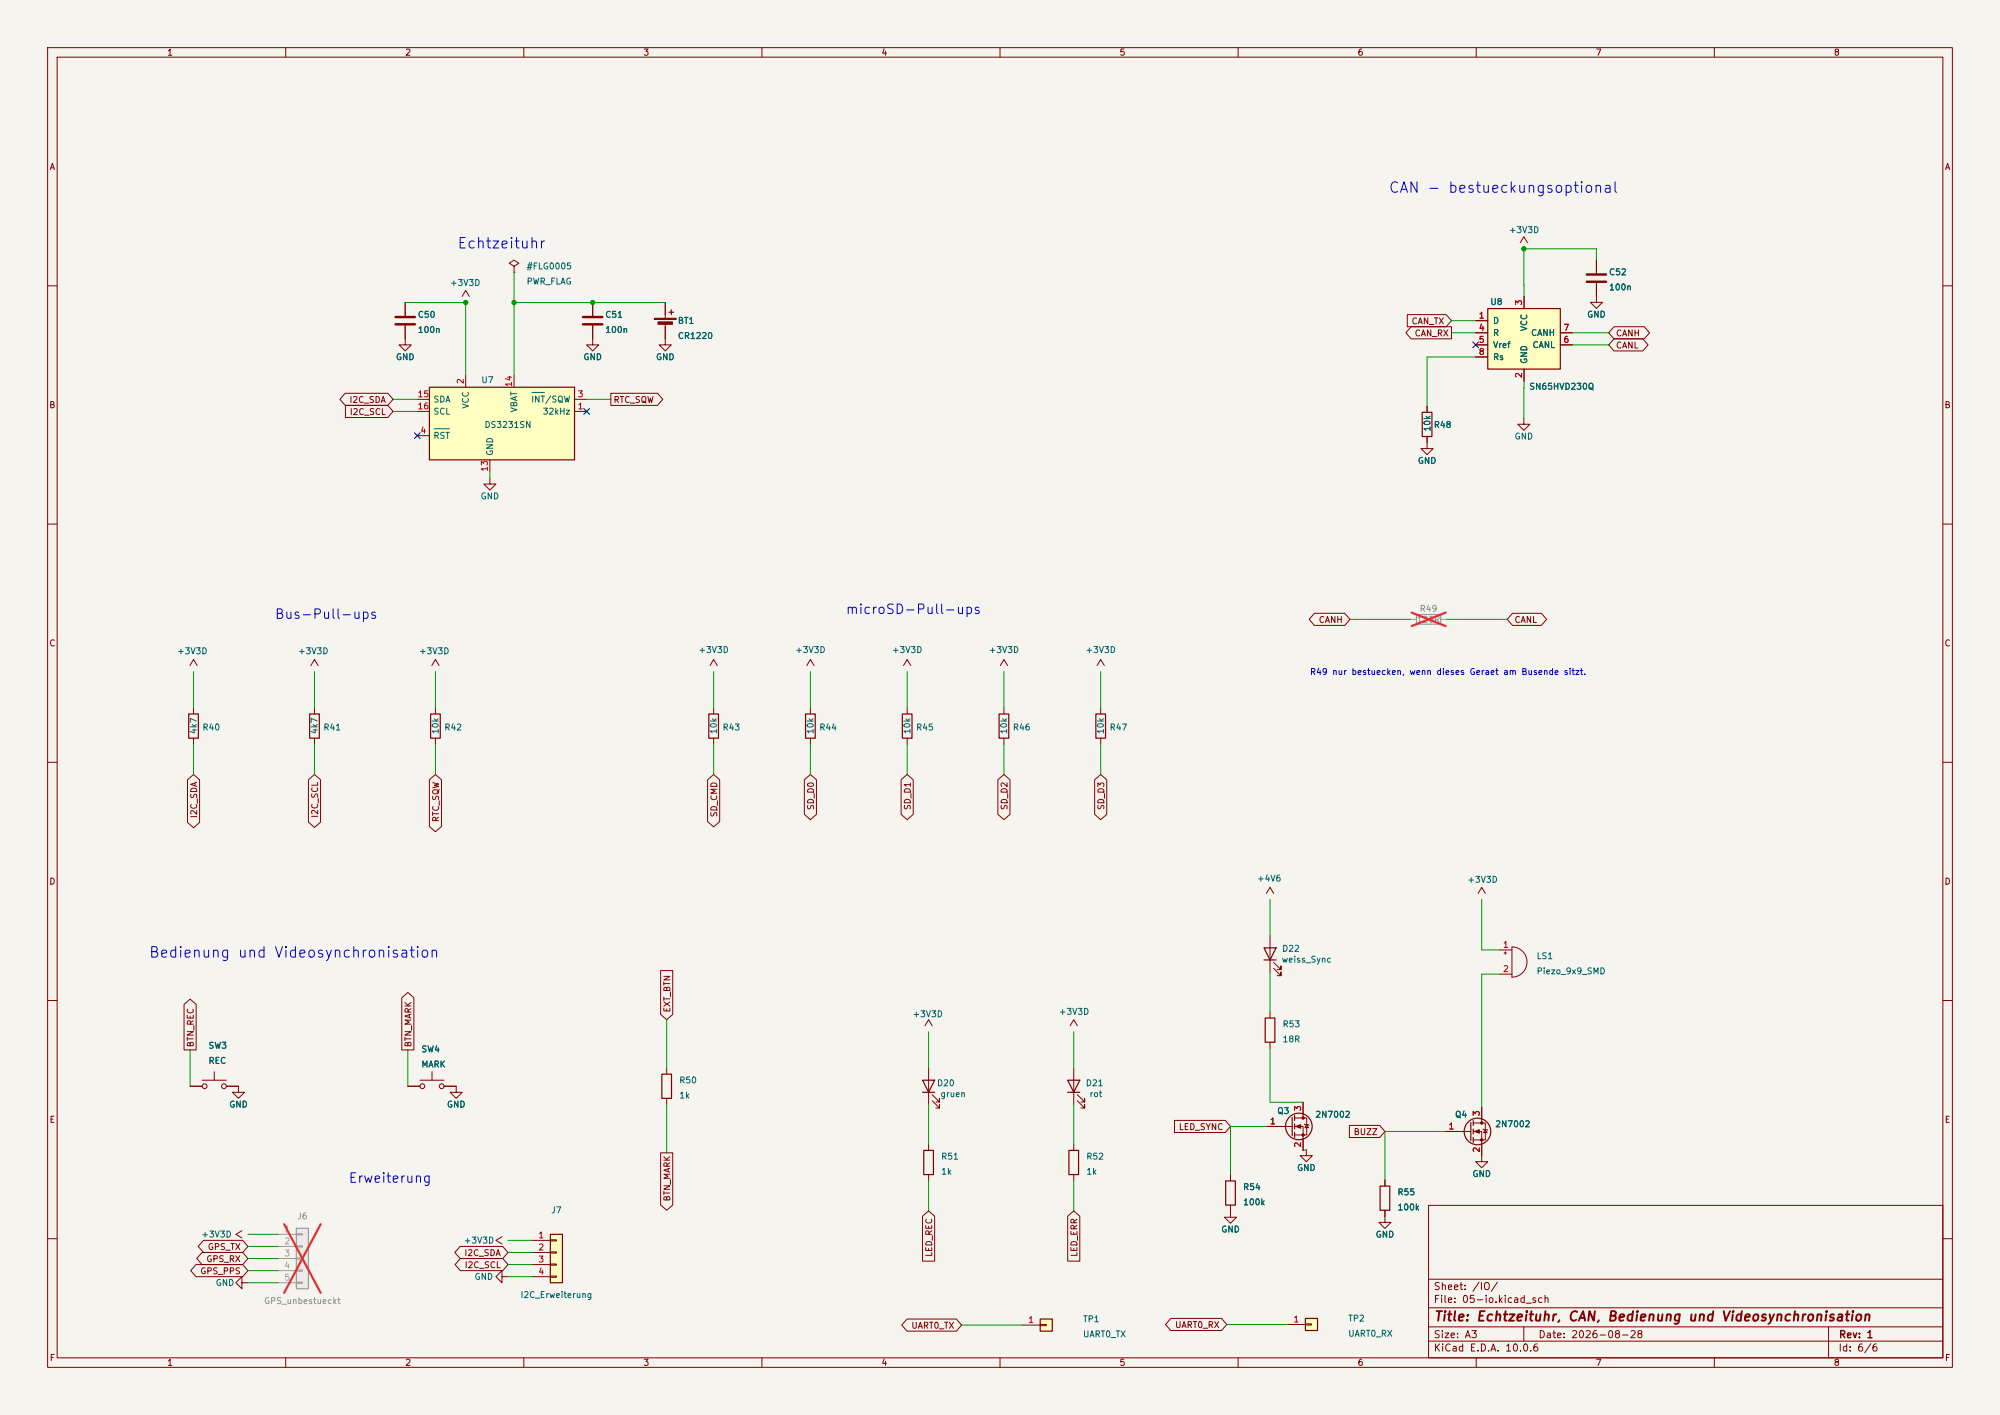
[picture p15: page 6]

R49 nur bestuecken, wenn dieses Geraet am Busende sitzt. CAN - bestueckungsoptional

Sheet: /IO/
File: 05-io.kicad_sch
Title: Echtzeituhr, CAN, Bedienung und Videosynchronisation

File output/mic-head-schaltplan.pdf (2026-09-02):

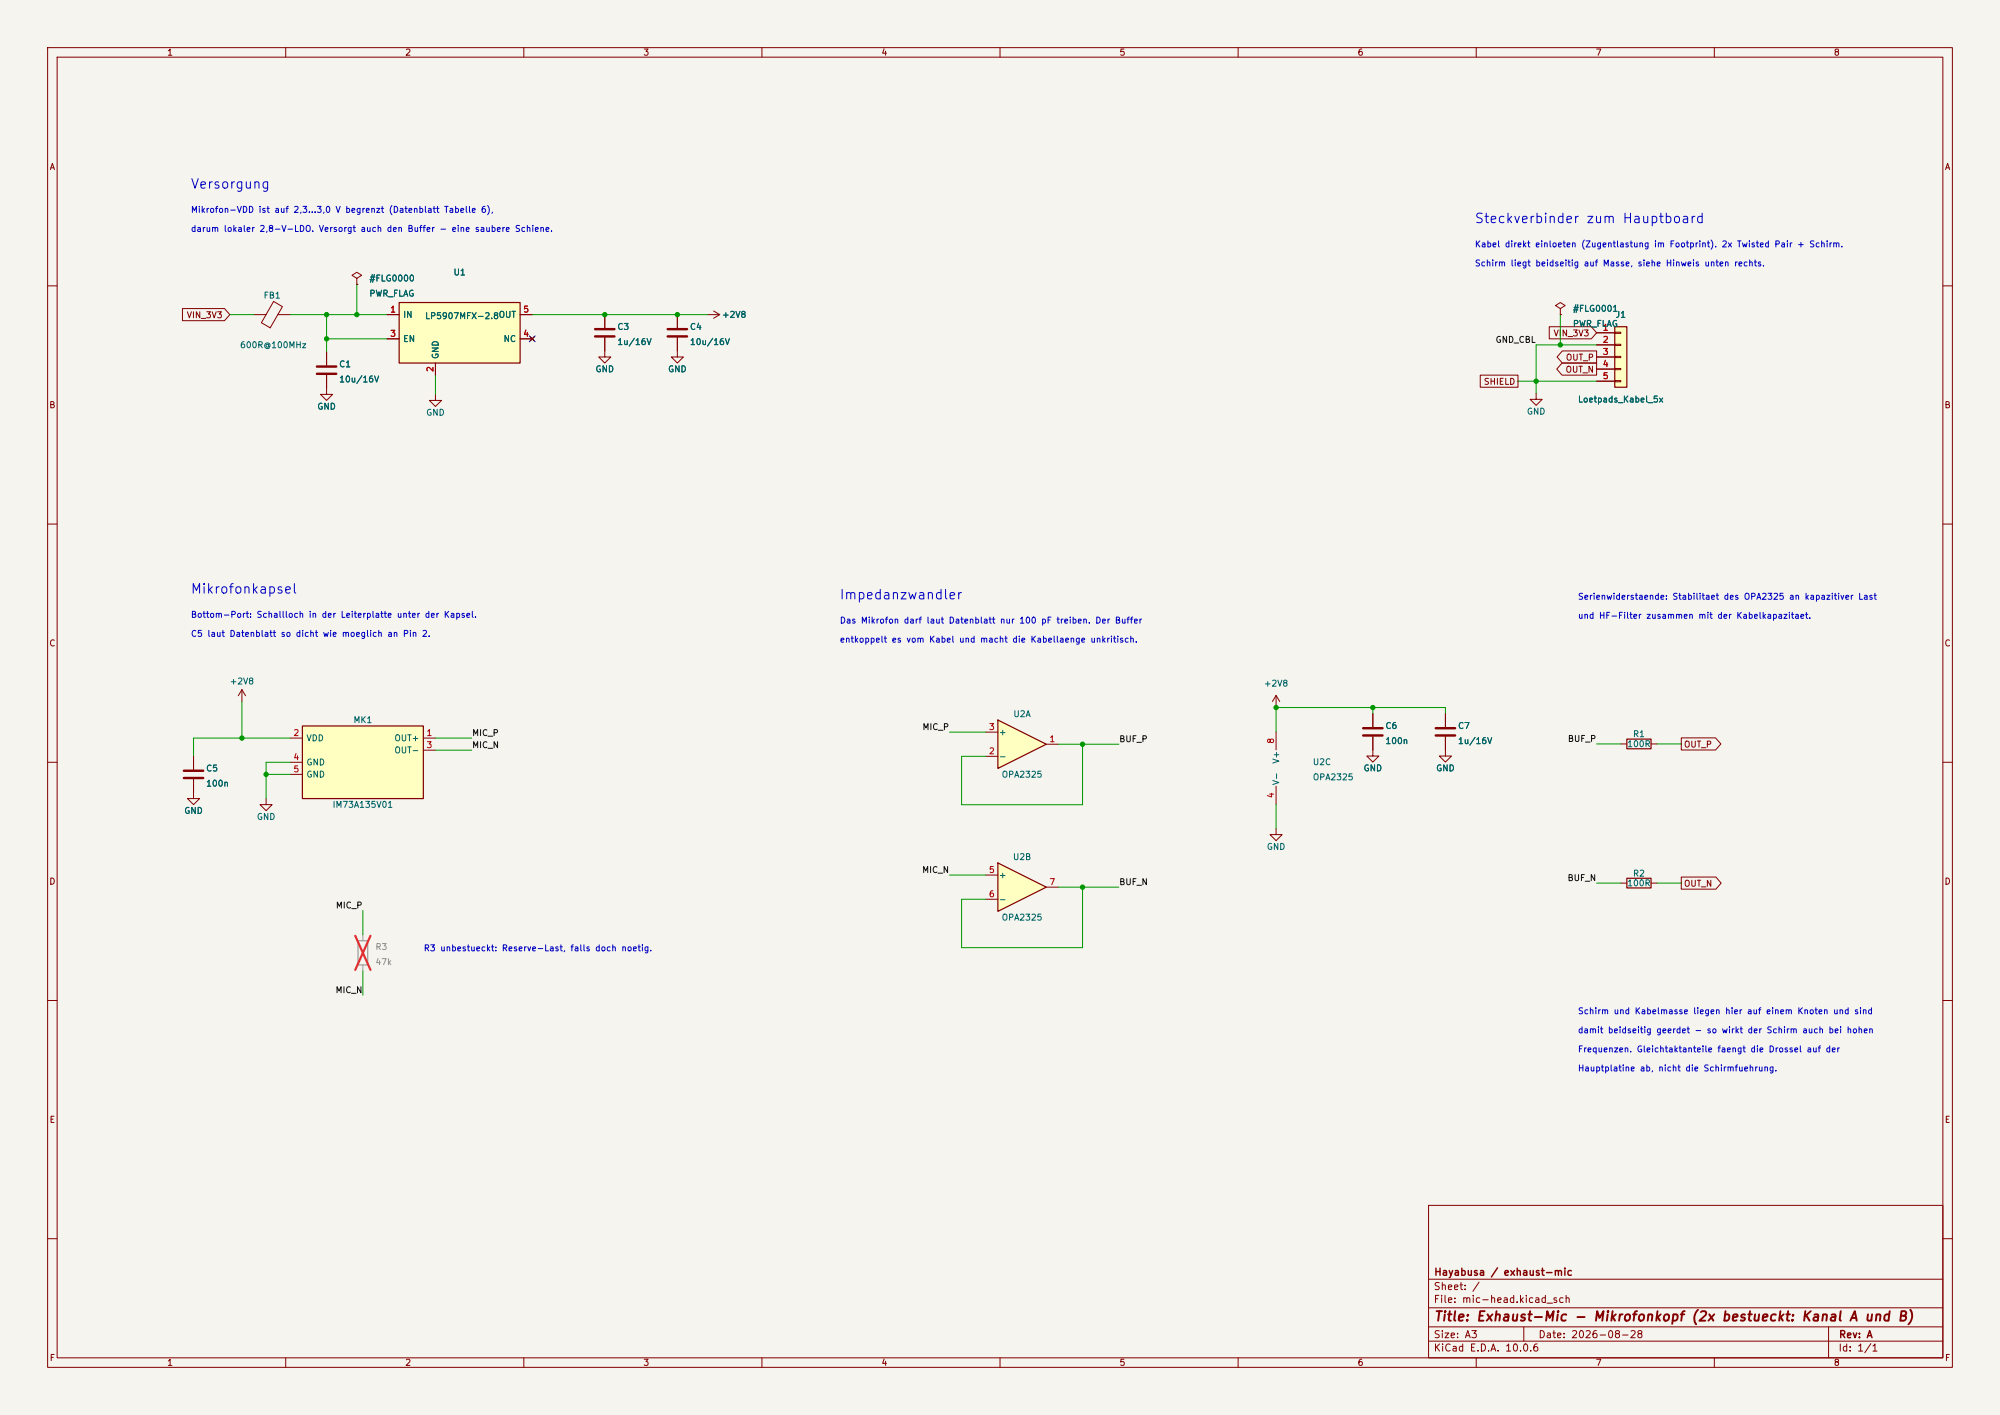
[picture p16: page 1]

Kabel direkt einloeten (Zugentlastung im Footprint). 2x Twisted Pair + Schirm. Serienwiderstaende: Stabilitaet des OPA2325 an kapazitiver Last Steckverbinder zum Hauptboard

Frequenzen. Gleichtaktanteile faengt die Drossel auf der Schirm und Kabelmasse liegen hier auf einem Knoten und sind

Hayabusa / exhaust-mic
Sheet: /
File: mic-head.kicad_sch
Title: Exhaust-Mic - Mikrofonkopf (2x bestueckt: Kanal A und B)

Size: A3 | Rev: A | F Date: 2026-08-28
KiCad E.D.A. 10.0.6 | Id: 1/1

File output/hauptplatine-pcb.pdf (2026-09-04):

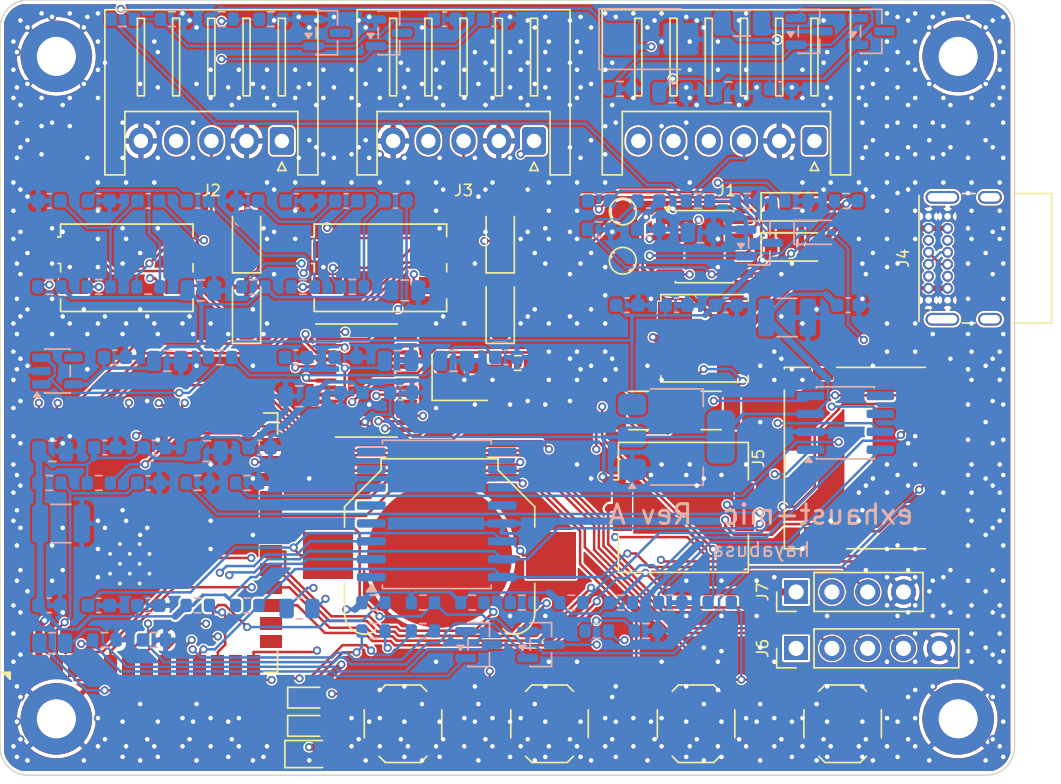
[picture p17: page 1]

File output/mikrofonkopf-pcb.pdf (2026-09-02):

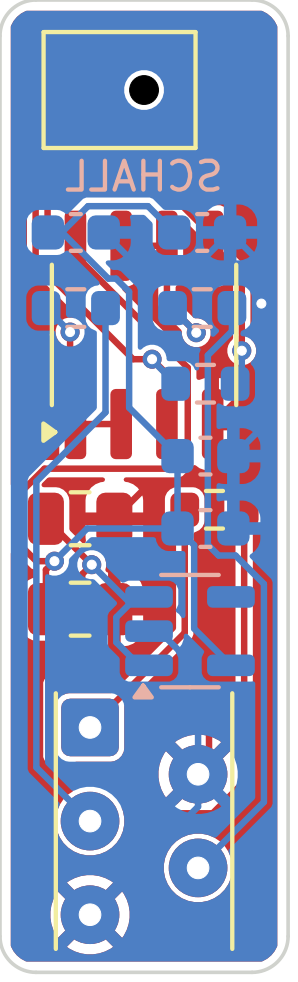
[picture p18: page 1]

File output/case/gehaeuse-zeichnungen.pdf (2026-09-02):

## Hauptgehaeuse Unterschale - Draufsicht (Masse in mm)

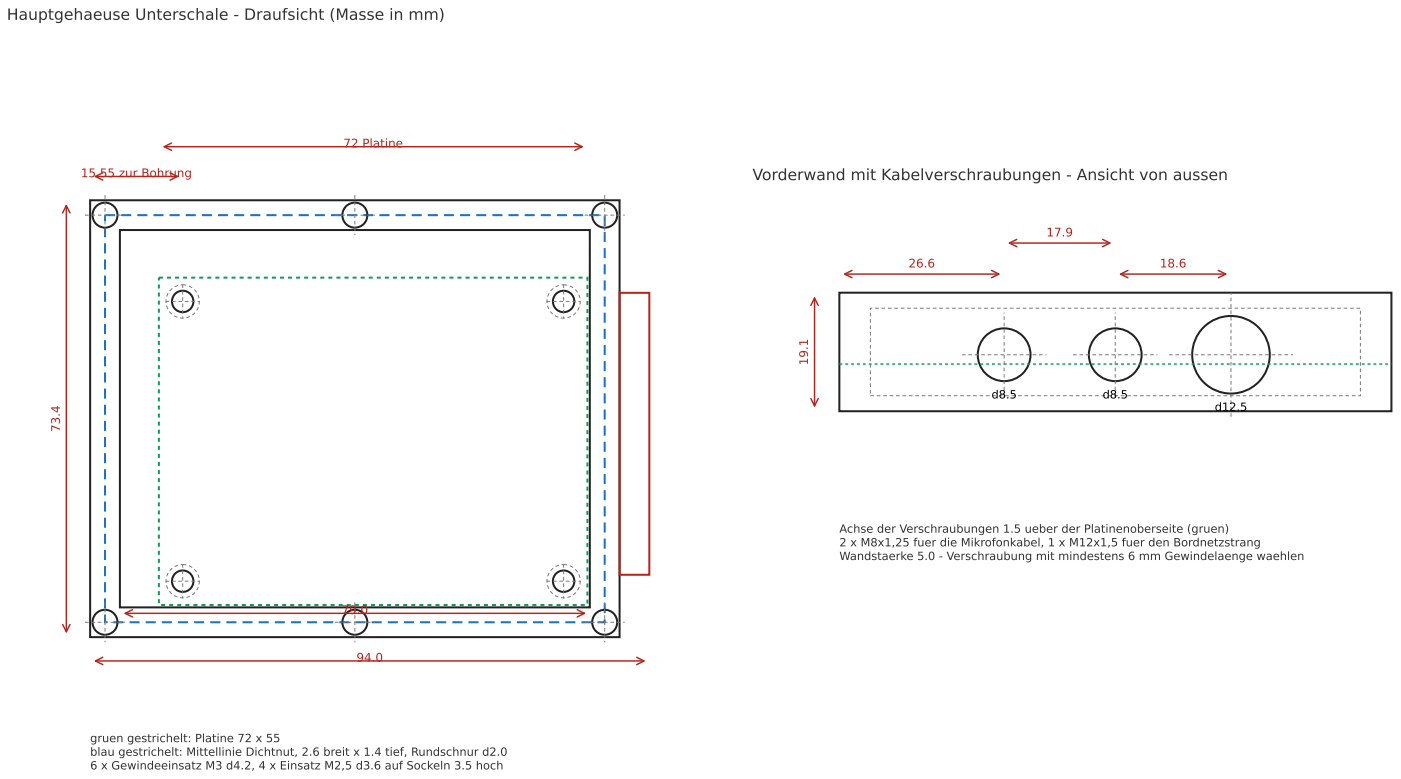
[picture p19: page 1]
72 Platine; 15.55 zur Bohrung

Vorderwand mit Kabelverschraubungen - Ansicht von aussen

Achse der Verschraubungen 1.5 ueber der Platinenoberseite (gruen)
2 x M8x1,25 fuer die Mikrofonkabel, 1 x M12x1,5 fuer den Bordnetzstrang
Wandstaerke 5.0 - Verschraubung mit mindestens 6 mm Gewindelaenge waehlen

gruen gestrichelt: Platine 72 x 55
blau gestrichelt: Mittellinie Dichtnut, 2.6 breit x 1.4 tief, Rundschnur d2.0
6 x Gewindeeinsatz M3 d4.2, 4 x Einsatz M2,5 d3.6 auf Sockeln 3.5 hoch

## Hauptgehaeuse Deckel - Ansicht von innen

## Deckel - Schnitt durch einen Taster

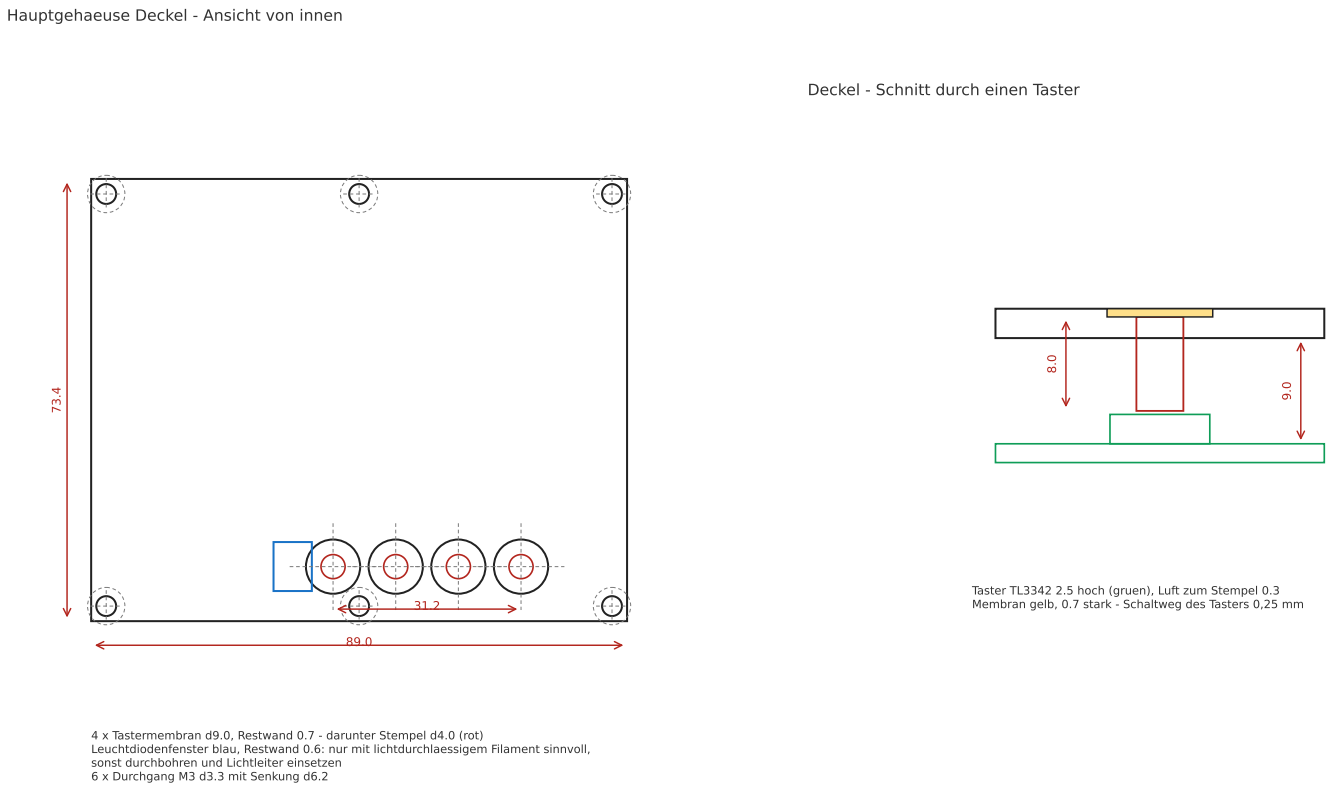
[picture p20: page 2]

Taster TL3342 2.5 hoch (gruen), Luft zum Stempel 0.3
Membran gelb, 0.7 stark - Schaltweg des Tasters 0,25 mm

4 x Tastermembran d9.0, Restwand 0.7 - darunter Stempel d4.0 (rot)
Leuchtdiodenfenster blau, Restwand 0.6: nur mit lichtdurchlaessigem Filament sinnvoll,
sonst durchbohren und Lichtleiter einsetzen
6 x Durchgang M3 d3.3 mit Senkung d6.2

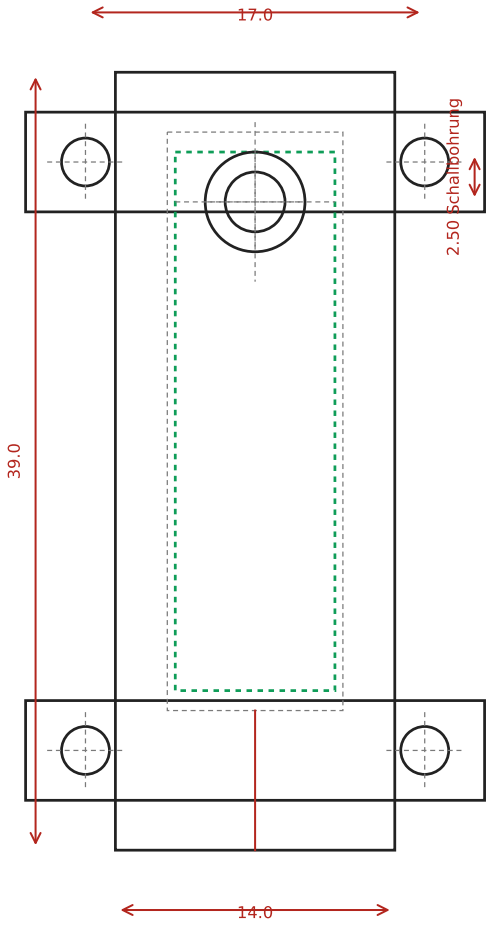
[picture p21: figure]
2.50 Schallbohrung

Rohr d14.0, Laenge 39.0, Trennebene in der Achse
Platine 8 x 27 gruen, Hohlraum 8.8 breit
Dichtsockel d5.0 aussen / d3.0 innen, drueckt gegen die Platinenrueckseite 4 x M2, Kabelkanal d4.2 (rot)

## Mikrofonkopf - Draufsicht auf die Trennebene


4.40 Schallweg

Abflachung auf der Schallseite bei z -6.0, 4 Gitterloecher d1.0 Kabelbindernut 3.0 breit x 1.2 tief bei y 32.0
blau: Rohrachse und Trennebene

## Mikrofonkopf - Schnitt in der Laengsachse

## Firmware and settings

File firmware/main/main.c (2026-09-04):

/* exhaust-mic: zweikanaliger Rekorder mit GoPro-Kopplung.
 *
 * Ablauf: Wandler und Karte hochfahren, dann auf drei Ausloeser warten -
 * die Taste am Geraet, die Kamera ueber Bluetooth LE und den Motor.
 * Jeder startet dieselbe Aufnahme.
 *
 * Umgesetzt: F1 (I2S per DMA), F2/F3 (WAV mit BEXT), F4 (Sekundenanker),
 * F5 (Wandler ueber I2C), F6 (Uebersteuerung), F7 (Zuendungsautomat),
 * F8 (Marker) sowie die GoPro-Kopplung. Offen: F9 WLAN und NTP, F10 CAN,
 * F11 Download - siehe firmware/README.md.
 */

#include <inttypes.h>
#include <string.h>

#include "audio.h"
#include "bedienung.h"
#include "esp_log.h"
#include "freertos/FreeRTOS.h"
#include "freertos/queue.h"
#include "freertos/task.h"
#include "gopro.h"
#include "i2cbus.h"
#include "pcm1863.h"
#include "speicher.h"
#include "zeitbasis.h"
#include "zuendung.h"

static const char *TAG = "main";

/* 16 kB je Schreibvorgang: gross genug, dass die Karte am Stueck
 * arbeitet, klein genug, dass der DMA-Vorlauf nicht ausgeht. */
#define BLOCK 16384

static QueueHandle_t BEFEHLE;      /* true = starten, false = stoppen */
static volatile bool ABSCHALTEN;   /* Zuendung ist aus, Datei zumachen */

/* Die Kamera hat ihren Zustand geaendert - das ist der Hauptweg: Video
 * starten, Aufnahme laeuft mit. Der Taster weiter unten ist nur der
 * Zusatz fuer die Gegenrichtung.
 *
 * Gerufen wird das aus dem NimBLE-Task, nicht aus einer Unterbrechung.
 * Deshalb xQueueSend und nicht xQueueSendFromISR - die ISR-Fassung
 * erwartet Unterbrechungskontext, und portYIELD_FROM_ISR aus einer
 * Aufgabe heraus ist schlicht falsch. */
static void gopro_meldet(bool laeuft, void *arg)
{
    xQueueSend(BEFEHLE, &laeuft, 0);
}

/* Der Motor ist die dritte Quelle neben Taster und Kamera: springt er an,
 * steigt die Bordspannung von der Ruhespannung auf die Ladespannung, und
 * genau das meldet der Automat als ZUENDUNG_MOTOR.
 *
 * ZUENDUNG_AUS geht nicht ueber die Warteschlange, sondern ueber ein
 * eigenes Kennzeichen: danach faellt die Versorgung, und die Datei muss
 * vorher zu sein - das darf nicht hinter anderen Befehlen anstehen. */
static void zuendung_meldet(zuendung_t zustand, void *arg)
{
    if (zustand == ZUENDUNG_AUS) {
        ABSCHALTEN = true;
        return;
    }
    bool laeuft = zustand == ZUENDUNG_MOTOR;
    xQueueSend(BEFEHLE, &laeuft, 0);
}

static void aufnahme_starten(void)
{
    if (speicher_laeuft()) {
        return;
    }
    struct tm jetzt;
    if (zeitbasis_lesen(&jetzt) != ESP_OK) {
        ESP_LOGE(TAG, "Uhr antwortet nicht, keine Aufnahme");
        led(LED_ERR, true);
        return;
    }
    /* TimeReference im BEXT zaehlt Samples seit Mitternacht. */
    uint64_t seit_mitternacht =
        ((uint64_t)jetzt.tm_hour * 3600 + jetzt.tm_min * 60 + jetzt.tm_sec) *
        AUDIO_RATE;
    if (speicher_datei_oeffnen(&jetzt, seit_mitternacht) != ESP_OK) {
        led(LED_ERR, true);
        return;
    }
    led(LED_REC, true);
    marker_ausloesen();
    speicher_notiz("%llu,marker,start", (unsigned long long)*audio_rahmenzaehler());
}

static void aufnahme_stoppen(void)
{
    if (!speicher_laeuft()) {
        return;
    }
    speicher_notiz("%llu,marker,stop", (unsigned long long)*audio_rahmenzaehler());
    speicher_datei_schliessen();
    led(LED_REC, false);
}

/* Schreibt, was der DMA liefert. Eigene Aufgabe, damit die Karte den
 * Rest des Systems nicht anhaelt. */
static void schreiber(void *arg)
{
    static uint8_t puffer[BLOCK];
    while (true) {
        size_t n = audio_lesen(puffer, sizeof puffer, 200);
        if (n && speicher_laeuft()) {
            if (speicher_schreiben(puffer, n) != ESP_OK) {
                led(LED_ERR, true);
                aufnahme_stoppen();
            }
        }
    }
}

/* Sekundenanker und Uebersteuerung. */
static void aufsicht(void *arg)
{
    zeit_anker_t letzter = {0}, jetzt;
    bool funk_gemeldet = false;
    while (true) {
        if (speicher_laeuft() && zeitbasis_anker(&jetzt) &&
            jetzt.sample != letzter.sample) {
            letzter = jetzt;
            speicher_notiz("%llu,uhr,%lld", (unsigned long long)jetzt.sample,
                           (long long)jetzt.utc);
        }
        /* Bricht die Funkstrecke waehrend einer Aufnahme ab, laeuft die
         * Aufnahme weiter - aber man soll es sehen. */
        bool funk_weg = speicher_laeuft() && gopro_zustand() != GOPRO_BEREIT;
        if (funk_weg != funk_gemeldet) {
            funk_gemeldet = funk_weg;
            speicher_notiz("%llu,gopro,%s",
                           (unsigned long long)*audio_rahmenzaehler(),
                           funk_weg ? "verbindung weg" : "verbindung wieder da");
        }
        float a = audio_spitze(0), b = audio_spitze(1);
        /* -0,5 dBFS. Darueber ist der Wandler praktisch am Anschlag. */
        led(LED_ERR, a > 0.944f || b > 0.944f || funk_weg);
        vTaskDelay(pdMS_TO_TICKS(100));
    }
}

void app_main(void)
{
    /* Zuerst die Selbsthaltung, vor allem anderen. Beim Anlassen bricht
     * die Zuendspannung ein; ohne PWR_HOLD faellt die Platine dann genau
     * in dem Moment aus, in dem die Aufnahme beginnen soll. */
    zuendung_selbsthaltung();

    BEFEHLE = xQueueCreate(4, sizeof(bool));

    ESP_ERROR_CHECK(bedienung_start());
    ESP_ERROR_CHECK(i2cbus_start());
    ESP_ERROR_CHECK(zeitbasis_start());
    ESP_ERROR_CHECK(pcm1863_start(AUDIO_RATE, 24));
    ESP_ERROR_CHECK(audio_start());
    zeitbasis_samplezaehler_setzen(audio_rahmenzaehler());
    pcm1863_takt_pruefen(NULL);

    if (speicher_start() != ESP_OK) {
        led(LED_ERR, true);
    }
    ESP_ERROR_CHECK(gopro_start(gopro_meldet, NULL));
    if (zuendung_start(zuendung_meldet, NULL) != ESP_OK) {
        /* Ohne den Automaten laeuft alles weiter - nur schaltet sich das
         * Geraet dann nicht mehr selbst ab. Das ist eine Meldung wert,
         * aber kein Grund, die Aufnahme zu verweigern. */
        led(LED_ERR, true);
    }

    xTaskCreate(schreiber, "schreiber", 4096, NULL, 6, NULL);
    xTaskCreate(aufsicht, "aufsicht", 4096, NULL, 3, NULL);
    ESP_LOGI(TAG, "bereit");

    while (true) {
        if (ABSCHALTEN) {
            ABSCHALTEN = false;
            ESP_LOGI(TAG, "Zuendung aus - Datei schliessen und abschalten");
            aufnahme_stoppen();
            zuendung_abschalten();
        }
        bool befehl;
        if (xQueueReceive(BEFEHLE, &befehl, pdMS_TO_TICKS(20)) == pdTRUE) {
            ESP_LOGI(TAG, "Kamera: %s", befehl ? "start" : "stop");
            befehl ? aufnahme_starten() : aufnahme_stoppen();
        }
        if (taste_rec_geholt()) {
            if (speicher_laeuft()) {
                aufnahme_stoppen();
                gopro_ausloesen(false);     /* Kamera mitnehmen */
            } else {
                aufnahme_starten();
                gopro_ausloesen(true);
            }
        }
        if (taste_mark_geholt() && speicher_laeuft()) {
            uint64_t s = *audio_rahmenzaehler();
            marker_ausloesen();
            speicher_notiz("%llu,marker,taste", (unsigned long long)s);
        }
    }
}

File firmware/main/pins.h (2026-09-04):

/* Erzeugt von firmware/tools/pins_aus_netzliste.py - nicht von Hand
 * aendern. Quelle ist der Schaltplan ueber output/main.net.
 *
 * Modul: ESP32-S3-WROOM-1-N8R2, 8 MB Flash, 2 MB PSRAM (quad).
 * Beim N8R2 sind GPIO35..37 frei - bei den Octal-PSRAM-Varianten
 * waeren sie belegt und die GPS-Stiftleiste unbrauchbar.
 */

#pragma once

#define PIN_I2S_BCK          5   /* Modulpin  5, Bittakt vom PCM1863, der ist Master */
#define PIN_I2S_LRCK         6   /* Modulpin  6, Wortakt vom PCM1863 */
#define PIN_I2S_DIN          7   /* Modulpin  7, Daten vom Wandler, aus Sicht des ESP32 Eingang */
#define PIN_PCM_INT         17   /* Modulpin 10, Sammelmeldung des PCM1863, u. a. Uebersteuerung */
#define PIN_I2C_SCL         18   /* Modulpin 11, gemeinsam: PCM1863 und DS3231 */
#define PIN_I2C_SDA          8   /* Modulpin 12 */
#define PIN_RTC_SQW         15   /* Modulpin  8, 1 Hz von der DS3231, latcht den Samplezaehler */
#define PIN_SD_CLK          14   /* Modulpin 22, SDMMC, 4 Bit */
#define PIN_SD_CMD          13   /* Modulpin 21 */
#define PIN_SD_D0           12   /* Modulpin 20 */
#define PIN_SD_D1           11   /* Modulpin 19 */
#define PIN_SD_D2           10   /* Modulpin 18 */
#define PIN_SD_D3            9   /* Modulpin 17 */
#define PIN_BTN_REC         21   /* Modulpin 23, Taster, gegen Masse */
#define PIN_BTN_MARK        47   /* Modulpin 24, Taster, gegen Masse */
#define PIN_LED_REC         48   /* Modulpin 25 */
#define PIN_LED_ERR         38   /* Modulpin 31 */
#define PIN_LED_SYNC        39   /* Modulpin 32, Blitz fuer den Videomarker */
#define PIN_BUZZ            40   /* Modulpin 33, Piezo ueber Q4 */
#define PIN_CAN_TX           4   /* Modulpin  4, an den SN65HVD230 */
#define PIN_CAN_RX          16   /* Modulpin  9 */
#define PIN_PGOOD           41   /* Modulpin 34, Sammelmeldung der Versorgung */
#define PIN_PWR_HOLD        42   /* Modulpin 35, Selbsthaltung: haelt EN/UVLO des LM5164 */
#define PIN_IGN_SENSE        1   /* Modulpin 39, Zuendung ueber Teiler, ADC1 */
#define PIN_VBAT_SENSE       2   /* Modulpin 38, Bordnetz ueber Teiler, ADC1 */
#define PIN_GPS_TX          35   /* Modulpin 28, Stiftleiste J6, unbestueckt */
#define PIN_GPS_RX          36   /* Modulpin 29 */
#define PIN_GPS_PPS         37   /* Modulpin 30 */
#define PIN_UART0_TX        43   /* Modulpin 37, Konsole */
#define PIN_UART0_RX        44   /* Modulpin 36 */

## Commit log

2026-08-28 modified: 01-power.kicad_sch modified: 02-analog.kicad_sch modified: 03-adc.kicad_sch modified: 04-mcu.kicad_sch modified: 05-io.kicad_sch modified: exhaust-mic.kicad_pro modified: exhaust-mic.kicad_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
    [01-power.kicad_sch, 02-analog.kicad_sch, 03-adc.kicad_sch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]
2026-08-31 modified: 01-power.kicad_sch modified: 02-analog.kicad_sch modified: 03-adc.kicad_sch modified: 04-mcu.kicad_sch modified: 05-io.kicad_sch modified: README.md modified: exhaust-mic.kicad_pcb modified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
    [01-power.kicad_sch, 02-analog.kicad_sch, 03-adc.kicad_sch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]
2026-08-31 modified: 01-power.kicad_sch modified: 02-analog.kicad_sch modified: 03-adc.kicad_sch modified: 04-mcu.kicad_sch modified: 05-io.kicad_sch new file: exhaust-mic.kicad_pro modified: exhaust-mic.kicad_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
    [01-power.kicad_sch, 02-analog.kicad_sch, 03-adc.kicad_sch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]
2026-08-31 Layout verdrahten, ERC/DRC bereinigen, Werkzeugkette auf KiCad 10
    Mikrofonkopf ist fertig verdrahtet (0 offene Verbindungen, 0 DRC-Fehler).
    Auf der Hauptplatine bleiben 16 Verbindungen offen, ebenfalls ohne
    DRC-Fehler; sie sind im interaktiven Router von KiCad zu schliessen.
    Schaltplan
    - 3 Speisepin-Fehler behoben (+4V6, ADC-AVDD, Uhrenbatterie brauchen ein
    Speiseflag - sie werden ueber Drossel, Ferrit bzw. Zelle gespeist und
    haben damit keine Quelle im Sinne der Regelpruefung)
    - Netzname GND_CHASSIS entfernt: lag auf demselben Knoten wie GND
    - TLV1117LV33 hatte einen Pin 4 fuer die Kuehlfahne, den es im Footprint
    SOT-223-3_TabPin2 nicht gibt - dort traegt Pad 2 die Fahne
    - Piezo von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
    [01-power.kicad_sch, 02-analog.kicad_sch, 03-adc.kicad_sch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]
2026-08-31 Freistellung der Kupferflaechen auf 0,15 mm: 16 -> 7 offene Verbindungen
    Mit 0,25 mm Freistellung zerfielen die Masseflaechen an jeder Leiterbahn in
    Inseln. Bei 0,15 mm - dem Wert der Netzklasse - quetscht sich das Kupfer
    zwischen die Bahnen und bleibt zusammenhaengend. Zusammen mit einem
    weiteren Routinglauf und Naehvias sinken die offenen Verbindungen auf der
    Hauptplatine von 16 auf 7, weiterhin ohne DRC-Fehler.
    Mindestbreite der Fuellung entsprechend auf 0,13 mm.
    [exhaust-mic.kicad_pcb]
2026-08-31 modified: 01-power.kicad_sch modified: 02-analog.kicad_sch modified: 03-adc.kicad_sch modified: 04-mcu.kicad_sch modified: 05-io.kicad_sch modified: exhaust-mic.kicad_pcb modified: exhaust-mic.kicad_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
    [01-power.kicad_sch, 02-analog.kicad_sch, 03-adc.kicad_sch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]
2026-08-31 Beschaffungsdaten aus DigiKey in die vorhandenen Schaltplaene eintragen
    Die Felder MPN, Hersteller und DigiKey werden nicht mehr geraten, sondern
    gegen die Produktdatenbank ermittelt und mit Lagerfilter geprueft. Grundlage
    sind die Schaltplandateien, wie sie auf der Platte liegen - die Generatoren
    sind inzwischen aelter und wurden nicht angefasst.
    tools/pick_digikey.py prueft jeden Treffer gegen die Parameter, die DigiKey
    mitliefert: Kapazitaet, Spannungsfestigkeit, Dielektrikum, Widerstandswert,
    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
    [01-power.kicad_sch, 02-analog.kicad_sch, 03-adc.kicad_sch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]
2026-08-31 Werte der Ersatztypen nachziehen und Felder auf die Platine uebertragen
    Vier Bauteile trugen nach dem Ersatz einen Wert, der nicht mehr zum
    eingebauten Typ passte: U2 (NCP1117ST33), U3 (LP5907MFX-3.3), U8
    (SN65HVD230Q) und Q1 (SI2309CDS). Die uebrigen fuenf Ersatztypen behalten
    ihren Wert - LM5164DDA, 24.576MHz, BZX84C15, PMEG3020 und OPA2325 sind
    Typbezeichnungen, die auch fuer die Ersatznummer gelten.
    Die Beschaffungsfelder standen bisher nur im Schaltplan. KiCads Abgleich
    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
    [01-power.kicad_sch, 05-io.kicad_sch, bom-mainboard.csv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]
2026-08-31 Footprints im Schaltplan auf den Stand des Layouts ziehen
    Neun Bauteile trugen im Schaltplan einen Footprint, der so nicht baubar ist.
    Das Layout hatte sie laengst ersetzt; jetzt steht es auch im Schaltplan:
    U5 TSSOP-30 4,4 x 9,7 / 0,65 -> 4,4 x 7,8 / 0,5 (Datenblatt)
    U6 ESP32-S2-WROOM -> ESP32-S3-WROOM-1
    L2, L3 L_CommonModeChoke_WE-SL2 -> L_CommonMode_WE-SL2
    J1..J3 TE Superseal 1.0 -> JST XH liegend
    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
    [01-power.kicad_sch, 02-analog.kicad_sch, 03-adc.kicad_sch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]
2026-08-31 Die beiden Symbolfehler geradeziehen, die der Abgleich meldete
    U2: Das Symbol exhaust-mic:TLV1117LV33 hatte vier Pins. Das SOT-223 hat drei
    Anschluesse und eine Kuehlfahne, die innen an Pin 2 haengt - Pin 4 gab es
    nie. Er lag am selben Netz wie Pin 2, elektrisch also folgenlos. Entfernt
    sind der Pin aus der Symbolkopie und aus dem Bauteil sowie die beiden
    Draehte und der Verbindungspunkt, die ihn an Pin 2 gefuehrt haben. Damit
    faellt auch der ERC-Fehler "Stromausgang gegen Stromausgang" weg.
    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
    [01-power.kicad_sch, 04-mcu.kicad_sch, exhaust-mic.kicad_pcb]
2026-08-31 Fehlende PWR_FLAG setzen - ERC auf beiden Platinen fehlerfrei
    KiCad prueft, ob jedes Versorgungsnetz von einem Ausgang gespeist wird. An
    fuenf Netzen sitzt keine Quelle, die es als solche erkennt: +4V6, AVDD
    (U5 Pin 14 des ADC-Reglers ueber die Ferritperle) und VBAT (U7 Pin 14, aus
    der Knopfzelle) auf der Hauptplatine, dazu Reglereingang und Masse beim
    Mikrofonkopf, die beide ueber das Kabel hereinkommen. Ein PWR_FLAG sagt dem
    ERC, dass das Absicht ist; an der Schaltung aendert es nichts.
    tools/add_pwr_flags.py schreibt die Bloecke von vorhandenen Symbolen ab und
    verschiebt sie, damit Aufbau und Schreibweise zur Datei passen - neue UUIDs,
    freie Referenzen, Blattpfad je Blatt, und beim Mikro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
    [01-power.kicad_sch, 03-adc.kicad_sch, 05-io.kicad_sch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]
2026-08-31 J4 auf den GCT USB4085-GF-A umstellen und das Layout nachziehen
    Den XKB-Typ zum bisherigen Footprint fuehrt DigiKey nicht. Der GCT
    USB4085-GF-A ist lagernd (80 000 Stueck), kostet 0,78 EUR - aber es ist
    keine gleiche Bauform: der XKB klebt mit einer Padreihe oben auf, der GCT
    steckt mit sechzehn Anschluessen in zwei versetzten Reihen durch die
    Platine. Am Motorrad ist das mechanisch die bessere Wahl; dafuer sperren
    die Bohrungen alle vier Lagen.
    tools/swap_footprint.py (neu) tauscht den Footprint auf der Platine und
    ordnet die Netze ueber die Padnamen aus der Netzliste zu. Danach ist der
    Autorouter einmal komplett durchgelaufen: 5 offene Verbindungen statt der
    7 vorher, und keine davon auf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
    [03-adc.kicad_sch, 04-mcu.kicad_sch, beschaffung-digikey.csv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]
2026-09-01 Versorgungsleitungen aufweiten
    freerouting verlegt alles in der Vorgabebreite von 0,18 mm. Bei 35 um
    Aussenkupfer sind das nach IPC-2221 rund 0,5 A bei 10 K Erwaermung - der
    ESP32 zieht in Sendespitzen annaehernd so viel allein.
    tools/widen_supply.py weitet im Nachgang auf: gestaffelt (0,5 / 0,4 / 0,3 /
    0,25 mm) und gruppenweise, die Gruppe mit dem groessten Strom zuerst, damit
    sie den Platz bekommt. Zurueckgenommen wird nach KiCads Regelpruefung, nicht
    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
    [exhaust-mic.kicad_pcb]
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
